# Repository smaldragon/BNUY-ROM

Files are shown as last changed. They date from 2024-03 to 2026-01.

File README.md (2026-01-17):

# BNUY-ROM

BNUY-ROM is an homebrew discrete logic mapper for the famicom/nes, which aims to have a similar level of capabilities to common ASIC mappers, while keeping a relatively low chip count. The mapper is designed to be modular, with features that can be included or ommitted depending on the needs of a game. It is similar to BNROM, hence the name.

Its capabilities are:

* Rewritable PRG-FLASH, 32K Window:
* * **39SF0x0** - Up to 512 KiB
* * **29FxxxFT** - Up to 2048KiB
* 32KiB PRG-RAM, 8K Window
* 8KiB, 32KiB or 128KiB of CHR-RAM, 4*2K Windows
* Fixed 4-Screen Nametable Arrangement
* Scanline IRQ, with MMC5-like timing

As an in-development mapper, there is currently no iNES number attributed, nor mainstream emulator support.

Render/schematic for the prototype tht version:

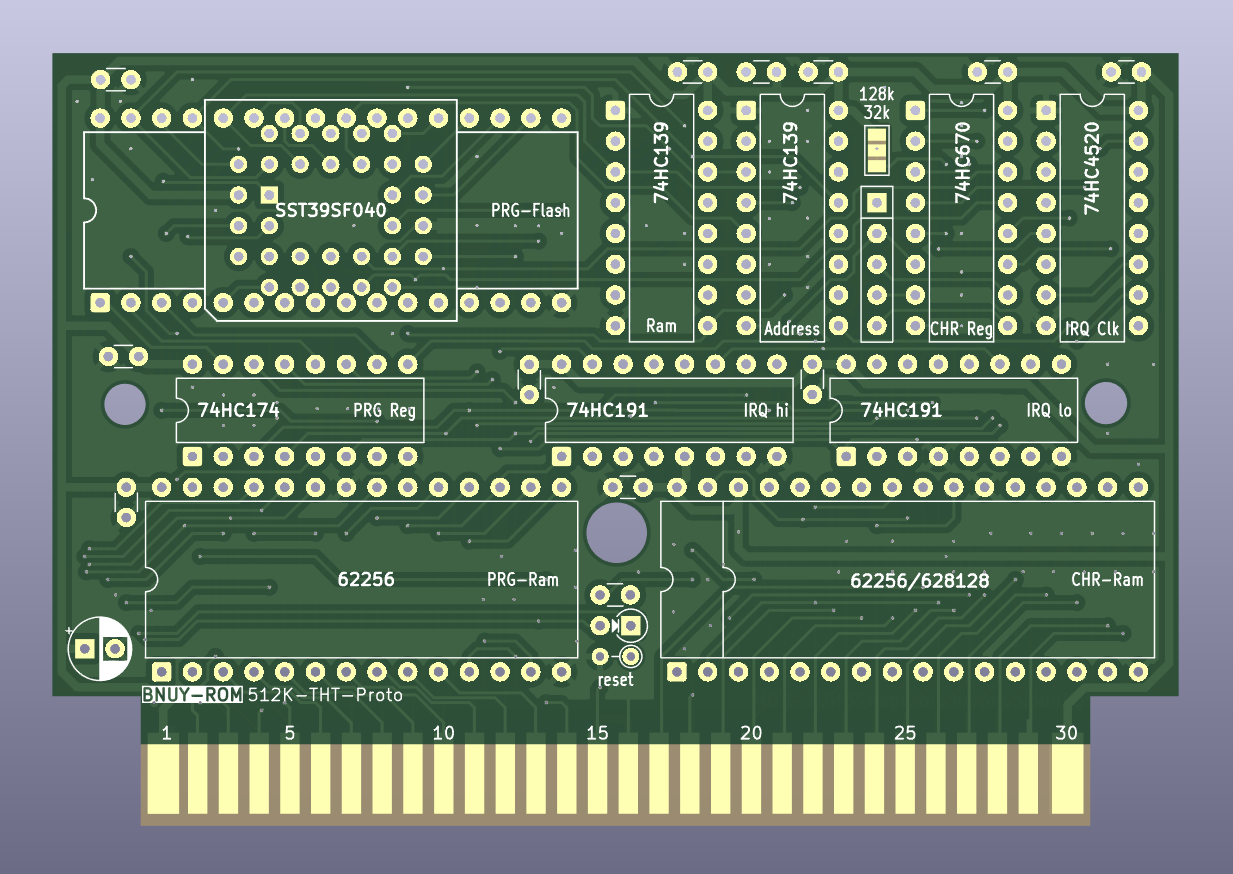
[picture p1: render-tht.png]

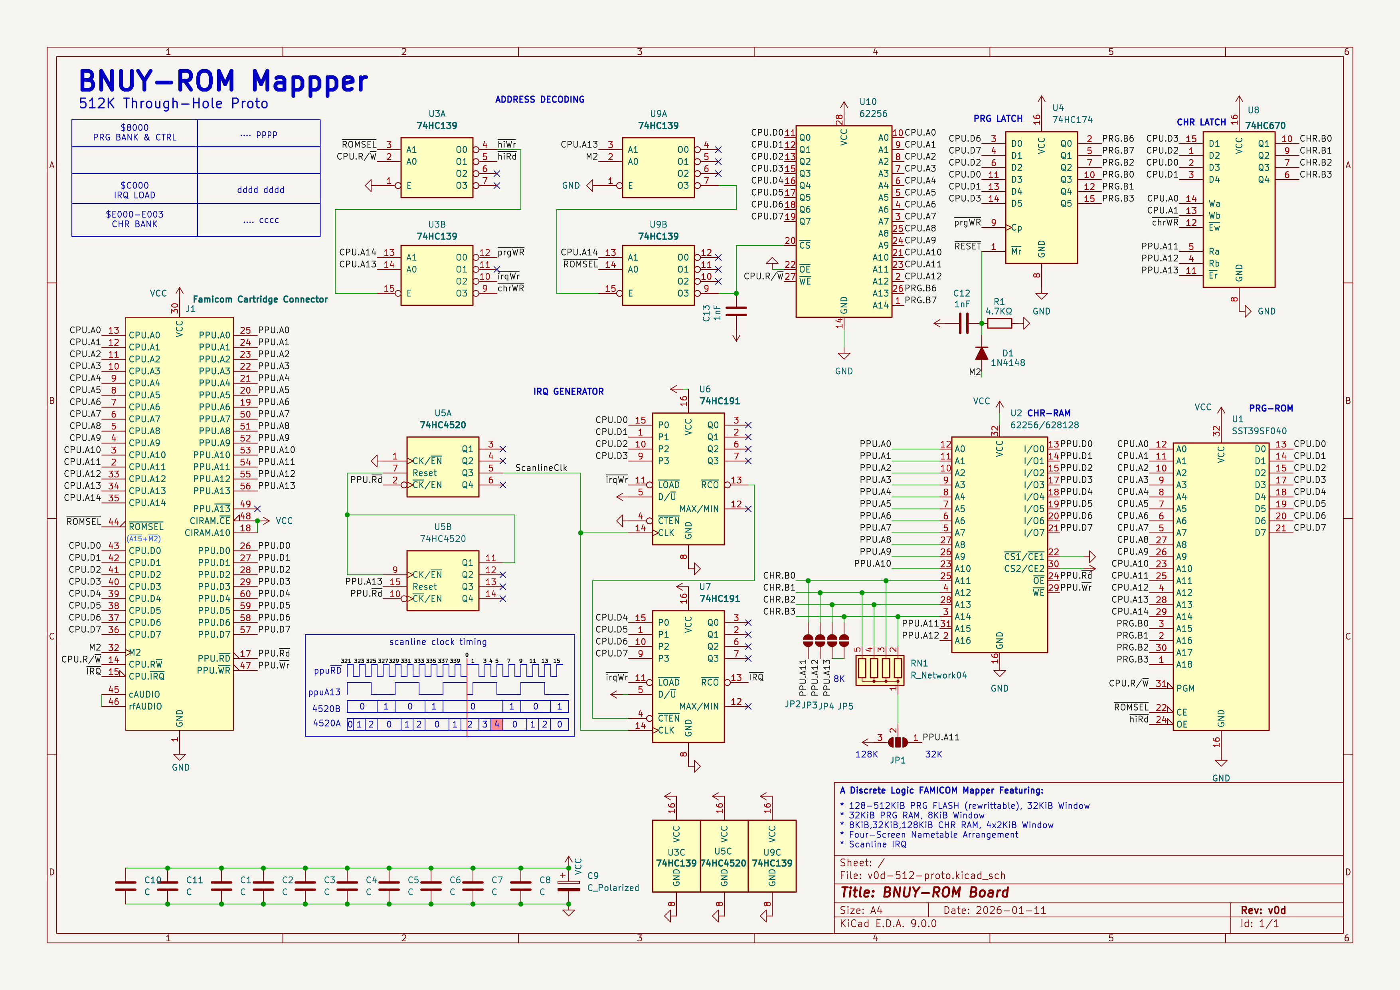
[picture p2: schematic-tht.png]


# Banks

* CPU $6000-$7FFF: 8KiB switchable PRG-RAM
* CPU $8000-$FFFF: 32 KiB switchable PRG-FLASH
* PPU $0000-$07FF: 2 KiB switchable CHR-RAM Bank
* PPU $0800-$0FFF: 2 KiB switchable CHR-RAM Bank
* PPU $1000-$17FF: 2 KiB switchable CHR-RAM Bank
* PPU $1800-$1FFF: 2 KiB switchable CHR-RAM Bank

# Registers

## PRG Banking ($8000-$9FFF, write)

This register controls the banking of PRG Flash and Ram.

```
A~100x xxxx xxxx xxxx ($8000)
D~7654 3210
  ---------
  RRPP PPPP
  ||++-++++--- PRG-Flash Bank
  ++-----------PRG-Ram Bank
```

## unused ($A000-$BFFF, write)

In previous iterations of the design, this area was used for a SAM2695 soundchip. It is now unused and avaliable for potential mapper additions.

## IRQ Counter Load ($C000-$DFFF, write)

This register will load a value into a scanline counter, which decrements once per active scanline at ppu cycle 4. The counter will continuously trigger an IRQ whenever its value is 0.

There is no mechanism to stop the counter, and it will underflow to 255 if an interrupt is ignored for 1 scanline. To stop the generator from firing, a value of 255 should be written every nmi.

```
A~110x xxxx xxxx xxxx ($C000)
D~7654 3210
  ---------
  IIII IIII
  ++++-++++- 8-bit scanline counter value
```

### Details

The 8-bit down counter is clocked by bit 2 of a prescaler counter, which increments on PPU reads with A13=1 and is cleared to zero on reads with A13=0. Normally one clock signal is generated by the prescaler per active scanline (including the pre-render scanline), but manual reads from PPU_DATA during VBlank or disabling rendering mid-frame will destabilize it. This can be overcome by reading once from A13=0 and twice from A13=1, followed by reloading the counter.

Overall the mechanism is similar to MMC5's scanline counter, but using relative values like the MMC3. Unlike the MMC3, this counter allows sprites to freely use either pattern table, including both while in 8x16 mode, and its timing simplifies scroll splits on consecutive scanlines.

It uses a x4520 to detect scanlines, and either a x40103 or two x191/x193s to hold the counter value.

## CHR Banking ($E000-$FFFF, write)

If present, these registers select one of 16 2KiB CHR-RAM banks, to use for each of the 4 PPU pattern table windows.

In **8k/linear mode**, the banking register is ommited. 16KiB of RAM are mapped to the PPU Address space, including 3840 bytes of "bonus ram" above the nametables, which the CPU may use to store values.

In **32K/shared mode**, Banks 0 and 15 are shared with the 4 nametables, and should be avoided unless special care is taken. This leaves 14 banks that can be freely distributed across the 4 windows. 

In **128K/independent mode**, the register is still 4 bits wide, but now each window has their own unique set of 16 banks (by connecting the top 2 address lines of memory to ppu A11/A12), this effectively quadruples the amount of avaliable chr-ram without adding a second register chip to the board. The first 2 windows share banks 15 with the nametables

```
A~111x xxxx xxxx xx00 ($E000)
	CHR Window 0
A~111x xxxx xxxx xx01 ($E001)
	CHR Window 1
A~111x xxxx xxxx xx10 ($E002)
	CHR Window 2
A~111x xxxx xxxx xx11 ($E003)
	CHR Window 3

D~7654 3210
  ---------
  .... BBBB
       ++++- CHR Bank Select
```

This uses a single x670 4x4 register. A second register could be added to the design for an oversize variant of 512KiB (shared) or 2048KiB (independent). A design with CHR-ROM could be used instead, at the cost of losing 4-screen nametable arrangement.

# Flash Programming

Flash programming is achieved by writing a specific sequence of command bytes to particular memory addresses, during this process flash memory cannot be read as normal, and conflicting mapper registers will have their values overwritten. As such, **flash programming code must be run from the internal 2KiB console ram, and all interrupts must be disabled**.

Flash writes operate by ANDing the written byte with the existing value in memory, with the only way to set a bit being by erasing an entire sector to `$FF`.

39SF commands listen to `A0-14`, which requires clobbering the IRQ Counter, while 29F commands listen only to `A0-A11`, allowing commands to fit in the unused `$A000-$BFFF` region.

For more information check the datasheet for your particular flash chip.

## Write Byte

### 39SF0x0

```
A~$8000 D~BANK
A~$D555 D~$AA
A~$AAAA D~$55
A~$D555 D~$A0
A~ADDR  D~DATA
```

### 29FxxxFT

```
A~$8000 D~BANK
A~$AAAA D~$AA
A~$A555 D~$55
A~$AAAA D~$A0
A~ADDR  D~DATA
```

## Erase Sector

### 39SF0x0

```
A~$8000 D~BANK
A~$D555 D~$AA
A~$AAAA D~$55
A~$D555 D~$80
A~$D555 D~$AA
A~$AAAA D~$55
A~ADDR  D~$30
```
**39SF0x0** uses uniform sectors of 4KiB,

### 29FxxxFT

```
A~$8000 D~BANK
A~$AAAA D~$AA
A~$A555 D~$55
A~$AAAA D~$80
A~$AAAA D~$AA
A~$A555 D~$55
A~ADDR  D~$30
```

**29FxxxFT** uses sectors of varying sizes depending on bank:
* Last Bank: 8KiB sectors at `$8000-$9FFF`, `$A000-$BFFF`, 16KiB sector at `$C000-$FFFF`
* Second-to-Last Bank: Single 32KiB sector
* All other banks: 64KiB sectors spanning 2 banks each.

## Write/Erase End Detect

The end of a write or erase operation can be detected by reading any memory address in flash until the same value is returned twice (toggle bit method).

## Software ID

Software ID mode can be entered to detect the manufacturer, size and type of flash chip, allowing for the same rom file to be compatible with multiple board configurations. Software ID is entered using the following command sequences:

### 39SF0x0

```
A~$8000 D~$00
A~$D555 D~$AA
A~$AAAA D~$55
A~$D555 D~$90
```

### 29FxxxFT

```
A~$8000 D~$00
A~$AAAA D~$AA
A~$A555 D~$55
A~$AAAA D~$90
```

Software ID mode is exited by writing `$F0` anywhere in flash.

### Device Code ($8001, read)

* `$B5` - 39SF010 (128KiB)
* `$B6` - 39SF020 (256KiB)
* `$B7` - 39SF040  (512KiB)
* `$51` - 29F200FT (256KiB)
* `$23` - 29F400FT (512KiB)
* `$D6` - 29F800FT (1024KiB)
* `$D2` - 29F160FT (2048KiB)

# NES 2.0 Description (tentative)

**Mapper ID**: *Unassigned*

**Flags 6 (nametable layout/flashing)**

```
D~3210
  ----
  F0BM
  | |+-- Hard-Wired Arragement
  | |      0: Vertical / 4-screen
  | |      1: Horizontal
  | +--- Uses Flash Saves
  |        0: No
  |        1: Yes
  +----- 4-Screen Arrangement
           0: Hard-Wired (using CIRAM)
           1: 4-Screen (using CHR-RAM)
```

Most games will have `%1010` here.

**Flags 8 (submapper)**

```
D~7654
  ----
  FICC
  ||++-- CHR Banking Mode
  ||        0: 8K/Linear (no banking)
  ||        1: 32K/Shared (all banks avaliable in every window)
  ||        2: 128K/Independent (all windows have unique sets of banks)
  |+---- Interrupt Generator
  |         0: No IRQ
  |         1: Has IRQ
  +----- Flash Memory Type
            0: 39SF0x0 (sizes of 128K, 256K, 512K)
            1: 29FxxxFT (sizes of 256K, 512K, 1024K, 2048K)
```

**PRG-ROM, PRG-RAM and CHR-RAM size**

Size should match the memory accessible on the board.

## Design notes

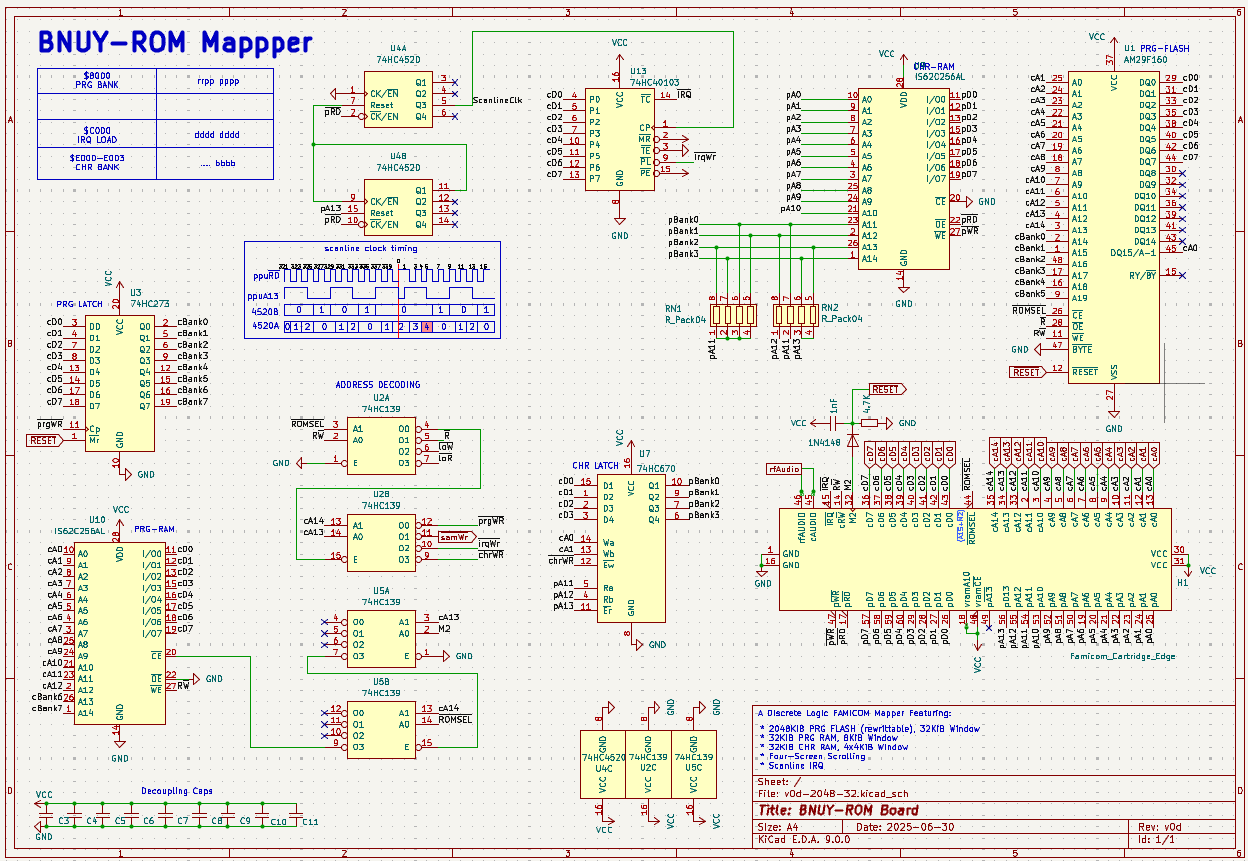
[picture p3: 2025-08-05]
schematic-smd.png

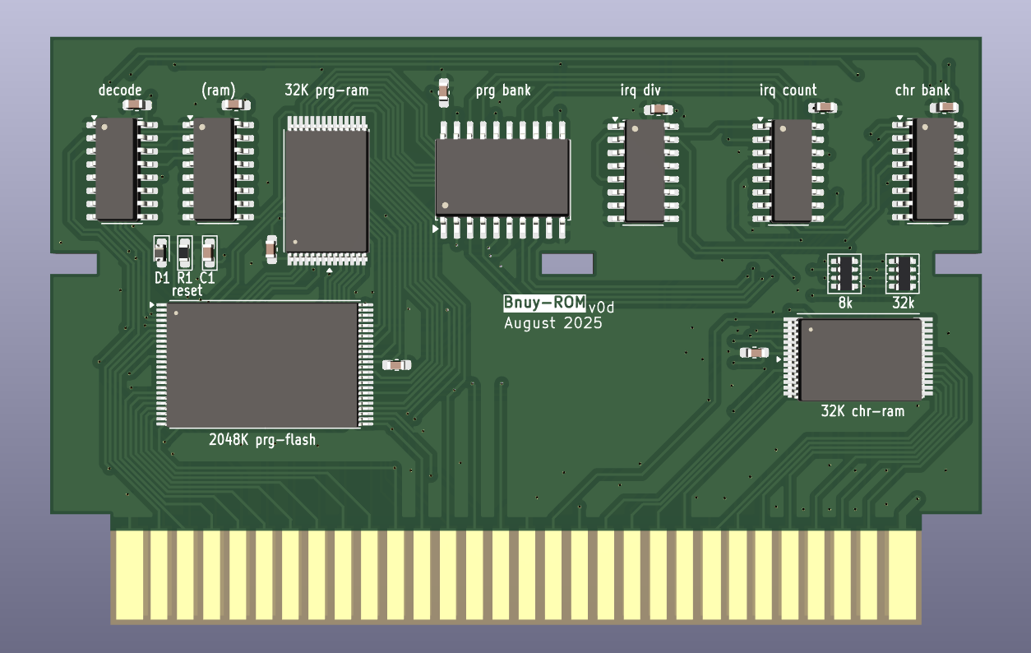
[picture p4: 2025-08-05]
render-smd.png

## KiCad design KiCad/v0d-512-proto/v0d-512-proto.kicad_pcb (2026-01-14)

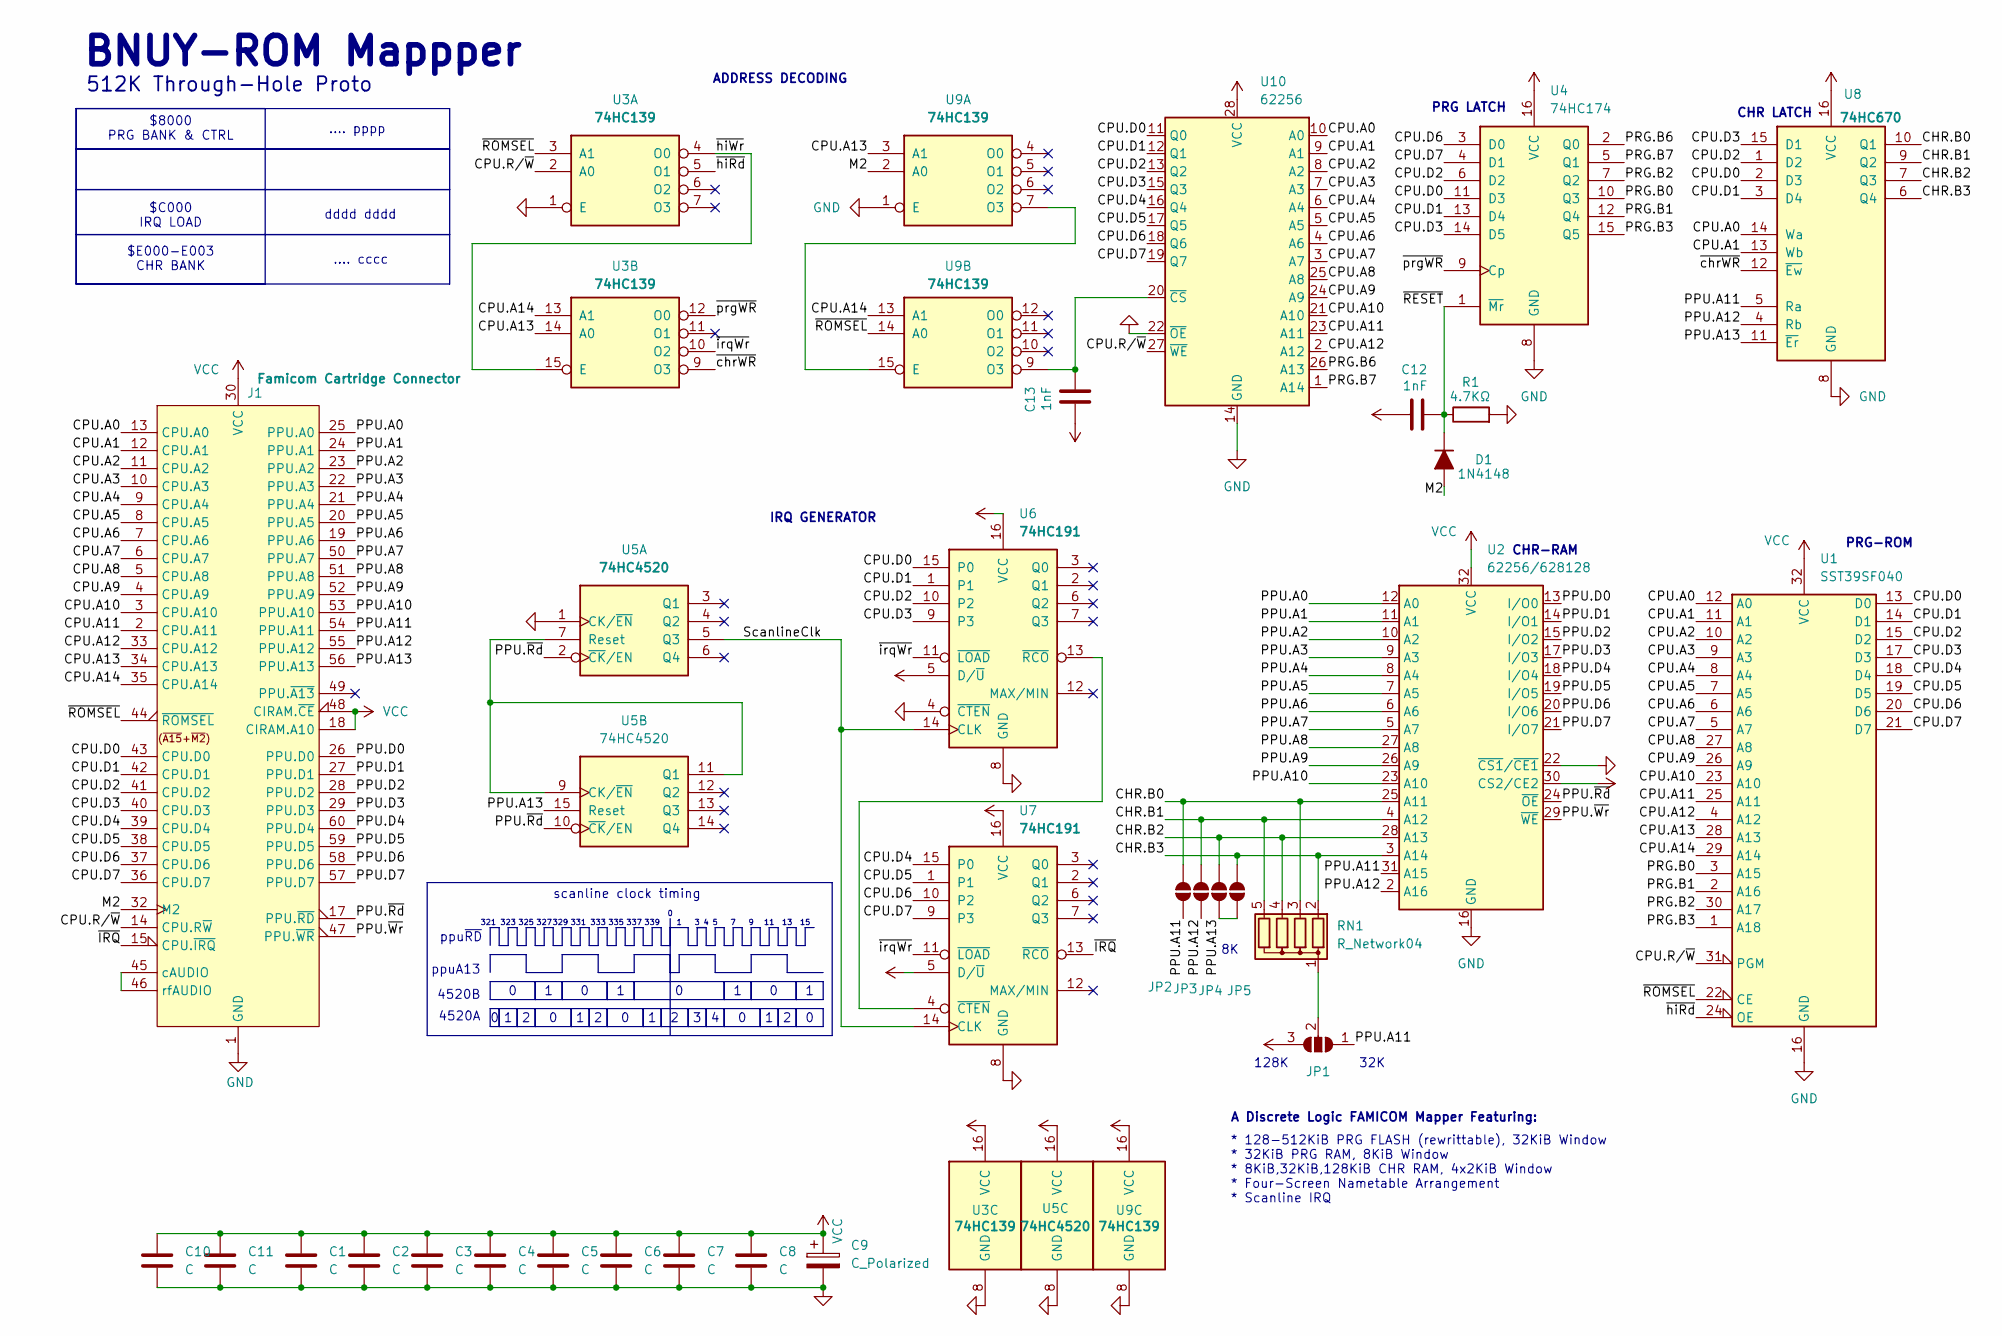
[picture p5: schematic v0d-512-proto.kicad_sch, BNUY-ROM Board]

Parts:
C1, C2, C3, C4, C5, C6, C7, C8, C10, C11: C; C_Disc_D3.0mm_W1.6mm_P2.50mm
C9: C_Polarized; CP_Radial_D5.0mm_P2.50mm
C12, C13: 1nF; C_Disc_D3.0mm_W1.6mm_P2.50mm
D1: 1N4148; D_DO-35_SOD27_P2.54mm_Vertical_AnodeUp
J1: Famicom Cartridge Connector; Famicom Cartridge Edge Connector (long legs)
JP1: SolderJumper_3_Open; SolderJumper-3_P1.3mm_Open_Pad1.0x1.5mm_NumberLabels
JP2, JP3, JP4, JP5: SolderJumper_2_Open; SolderJumper-2_P1.3mm_Open_Pad1.0x1.5mm
R1: 4.7KΩ; R_Axial_DIN0204_L3.6mm_D1.6mm_P2.54mm_Vertical
RN1: R_Network04; R_Array_SIP5
U1: SST39SF040; PLCC-DIP-32_THT-Socket
U2: 62256/628128; DIP-32_W15.24mm
U3, U9: 74HC139; DIP-16_W7.62mm
U4: 74HC174; DIP-16_W7.62mm
U5: 74HC4520; DIP-16_W7.62mm
U6, U7: 74HC191; DIP-16_W7.62mm
U8: 74HC670; DIP-16_W7.62mm
U10: 62256; DIP-28_W15.24mm

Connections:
/CHR.B0: JP2.1 (A), RN1.3 (R2), U2.25 (A11), U8.10 (Q1)
/CHR.B1: JP3.1 (A), RN1.5 (R4), U2.4 (A12), U8.9 (Q2)
/CHR.B2: JP4.1 (A), RN1.4 (R3), U2.28 (A13), U8.7 (Q3)
/CHR.B3: JP5.1 (A), RN1.2 (R1), U2.3 (A14), U8.6 (Q4)
/CPU.A0: J1.13 (CPU.A0), U1.12 (A0), U8.14 (Wa), U10.10 (A0)
/CPU.A1: J1.12 (CPU.A1), U1.11 (A1), U8.13 (Wb), U10.9 (A1)
/CPU.A2: J1.11 (CPU.A2), U1.10 (A2), U10.8 (A2)
/CPU.A3: J1.10 (CPU.A3), U1.9 (A3), U10.7 (A3)
/CPU.A4: J1.9 (CPU.A4), U1.8 (A4), U10.6 (A4)
/CPU.A5: J1.8 (CPU.A5), U1.7 (A5), U10.5 (A5)
/CPU.A6: J1.7 (CPU.A6), U1.6 (A6), U10.4 (A6)
/CPU.A7: J1.6 (CPU.A7), U1.5 (A7), U10.3 (A7)
/CPU.A8: J1.5 (CPU.A8), U1.27 (A8), U10.25 (A8)
/CPU.A9: J1.4 (CPU.A9), U1.26 (A9), U10.24 (A9)
/CPU.A10: J1.3 (CPU.A10), U1.23 (A10), U10.21 (A10)
/CPU.A11: J1.2 (CPU.A11), U1.25 (A11), U10.23 (A11)
/CPU.A12: J1.33 (CPU.A12), U1.4 (A12), U10.2 (A12)
/CPU.A13: J1.34 (CPU.A13), U1.28 (A13), U3.14 (A0), U9.3 (A1)
/CPU.A14: J1.35 (CPU.A14), U1.29 (A14), U3.13 (A1), U9.13 (A1)
/CPU.D0: J1.43 (CPU.D0), U1.13 (D0), U4.11 (D3), U6.15 (P0), U8.2 (D3), U10.11 (Q0)
/CPU.D1: J1.42 (CPU.D1), U1.14 (D1), U4.13 (D4), U6.1, U8.3 (D4), U10.12 (Q1)
/CPU.D2: J1.41 (CPU.D2), U1.15 (D2), U4.6 (D2), U6.10 (P2), U8.1 (D2), U10.13 (Q2)
/CPU.D3: J1.40 (CPU.D3), U1.17 (D3), U4.14 (D5), U6.9 (P3), U8.15 (D1), U10.15 (Q3)
/CPU.D4: J1.39 (CPU.D4), U1.18 (D4), U7.15 (P0), U10.16 (Q4)
/CPU.D5: J1.38 (CPU.D5), U1.19 (D5), U7.1, U10.17 (Q5)
/CPU.D6: J1.37 (CPU.D6), U1.20 (D6), U4.3 (D0), U7.10 (P2), U10.18 (Q6)
/CPU.D7: J1.36 (CPU.D7), U1.21 (D7), U4.4 (D1), U7.9 (P3), U10.19 (Q7)
/CPU.R/~W: J1.14 (CPU.R~W), U1.31 (PGM), U3.2 (A0), U10.27 (~WE)
/M2: D1.2 (A), J1.32 (M2), U9.2 (A0)
/PPU.A0: J1.25 (PPU.A0), U2.12 (A0)
/PPU.A1: J1.24 (PPU.A1), U2.11 (A1)
/PPU.A2: J1.23 (PPU.A2), U2.10 (A2)
/PPU.A3: J1.22 (PPU.A3), U2.9 (A3)
/PPU.A4: J1.21 (PPU.A4), U2.8 (A4)
/PPU.A5: J1.20 (PPU.A5), U2.7 (A5)
/PPU.A6: J1.19 (PPU.A6), U2.6 (A6)
/PPU.A7: J1.50 (PPU.A7), U2.5 (A7)
/PPU.A8: J1.51 (PPU.A8), U2.27 (A8)
/PPU.A9: J1.52 (PPU.A9), U2.26 (A9)
/PPU.A10: J1.53 (PPU.A10), U2.23 (A10)
/PPU.A11: J1.54 (PPU.A11), JP1.1 (A), JP2.2 (B), U2.31 (A15), U8.5 (Ra)
/PPU.A12: J1.55 (PPU.A12), JP3.2 (B), U2.2 (A16), U8.4 (Rb)
/PPU.A13: J1.56 (PPU.A13), JP4.2 (B), JP5.2 (B), U5.15 (Reset), U8.11 (~Er)
/PPU.D0: J1.26 (PPU.D0), U2.13 (I/O0)
/PPU.D1: J1.27 (PPU.D1), U2.14 (I/O1)
/PPU.D2: J1.28 (PPU.D2), U2.15 (I/O2)
/PPU.D3: J1.29 (PPU.D3), U2.17 (I/O3)
/PPU.D4: J1.60 (PPU.D4), U2.18 (I/O4)
/PPU.D5: J1.59 (PPU.D5), U2.19 (I/O5)
/PPU.D6: J1.58 (PPU.D6), U2.20 (I/O6)
/PPU.D7: J1.57 (PPU.D7), U2.21 (I/O7)
/PPU.~Rd: J1.17 (PPU.~RD), U2.24 (~OE), U5.2 (~CK/EN), U5.10 (~CK/EN)
/PPU.~Wr: J1.47 (PPU.~WR), U2.29 (~WE)
/PRG.B0: U1.3 (A15), U4.10 (Q3)
/PRG.B1: U1.2 (A16), U4.12 (Q4)
/PRG.B2: U1.30 (A17), U4.7 (Q2)
/PRG.B3: U1.1 (A18), U4.15 (Q5)
/PRG.B6: U4.2 (Q0), U10.26 (A13)
/PRG.B7: U4.5 (Q1), U10.1 (A14)
/ScanlineClk: U5.5 (Q3), U6.14 (CLK), U7.14 (CLK)
/~IRQ: J1.15 (CPU.~IRQ), U7.13 (~RCO)
/~RESET: C12.2, D1.1 (K), R1.1, U4.1 (~Mr)
/~ROMSEL: J1.44 (~ROMSEL), U1.22 (CE), U3.3 (A1), U9.14 (A0)
/~chrWR: U3.9 (O3), U8.12 (~Ew)
/~hiRd: U1.24 (OE), U3.5 (O1)
/~hiWr: U3.4 (O0), U3.15 (E)
/~irqWr: U3.10 (O2), U6.11 (~LOAD), U7.11 (~LOAD)
/~prgWR: U3.12 (O0), U4.9 (Cp)
GND: C1.2, C2.2, C3.2, C4.2, C5.2, C6.2, C7.2, C8.2, C9.2, C10.2, C11.2, J1.1 (GND), J1.16 (GND), R1.2, U1.16 (GND), U2.16 (GND), U2.22 (~CS1/~CE1), U3.1 (E), U3.8 (GND), U4.8 (GND), U5.1 (CK/~EN), U5.8 (GND), U6.4 (~CTEN), U6.8 (GND), U7.8 (GND), U8.8 (GND), U9.1 (E), U9.8 (GND), U10.14 (GND), U10.22 (~OE)
unnamed: J1.45 (cAUDIO), J1.46 (rfAUDIO)
unnamed: JP1.2 (C), RN1.1 (common)
unnamed: U5.7 (Reset), U5.9 (CK/~EN), U5.11 (Q1)
unnamed: U6.13 (~RCO), U7.4 (~CTEN)
unnamed: U9.7 (O3), U9.15 (E)
unnamed: C13.2, U9.9 (O3), U10.20 (~CS)
VCC: C1.1, C2.1, C3.1, C4.1, C5.1, C6.1, C7.1, C8.1, C9.1, C10.1, C11.1, C12.1, C13.1, J1.18 (CIRAM.A10), J1.30 (VCC), J1.31 (VCC), J1.48 (CIRAM.~CE), JP1.3 (B), U1.32 (VCC), U2.30 (CS2/CE2), U2.32 (VCC), U3.16 (VCC), U4.16 (VCC), U5.16 (VCC), U6.5 (D/~U), U6.16 (VCC), U7.5 (D/~U), U7.16 (VCC), U8.16 (VCC), U9.16 (VCC), U10.28 (VCC)

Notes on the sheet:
BNUY-ROM Mappper
335
321
.... pppp
* 128-512KiB PRG FLASH (rewrittable), 32KiB Window * 32KiB PRG RAM, 8KiB Window * 8KiB,32KiB,128KiB CHR RAM, 4x2KiB Window * Four-Screen Nametable Arrangement * Scanline IRQ
325
512K Through-Hole Proto
4520B
ADDRESS DECODING
327
339
ppuA13
CHR-RAM
dddd dddd
333
337
.... cccc
4520A
329
CHR LATCH
323
128K
A Discrete Logic FAMICOM Mapper Featuring:
PRG-ROM
scanline clock timing
IRQ GENERATOR
PRG LATCH
32K
331
ppu~{RD}
$8000 PRG BANK & CTRL $C000 IRQ LOAD $E000-E003 CHR BANK

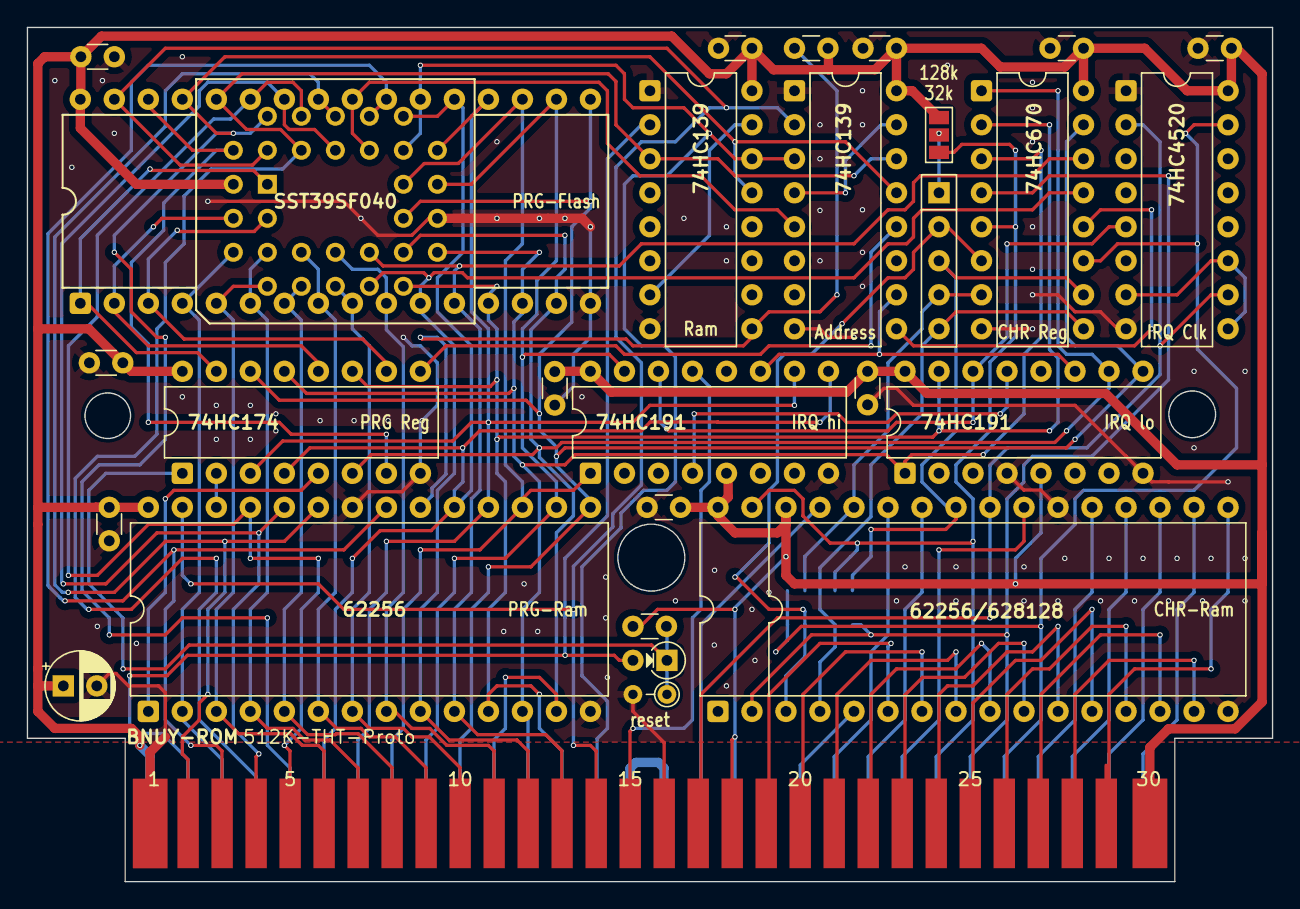
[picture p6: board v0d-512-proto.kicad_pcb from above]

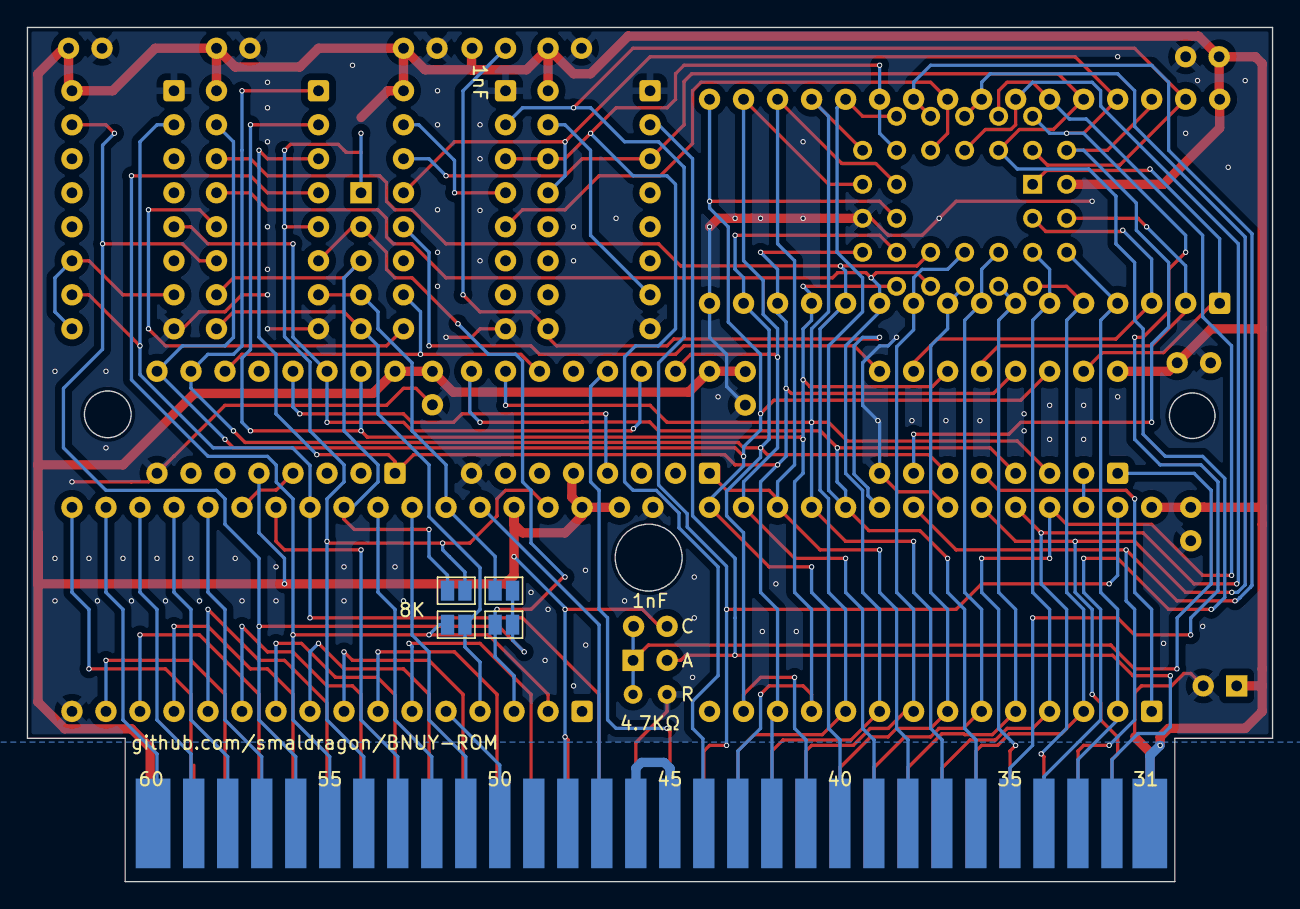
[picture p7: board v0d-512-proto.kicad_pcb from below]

Board: 2 copper layers, 93.0 x 63.8 mm, 32 parts (4 on the bottom side), 76 nets.

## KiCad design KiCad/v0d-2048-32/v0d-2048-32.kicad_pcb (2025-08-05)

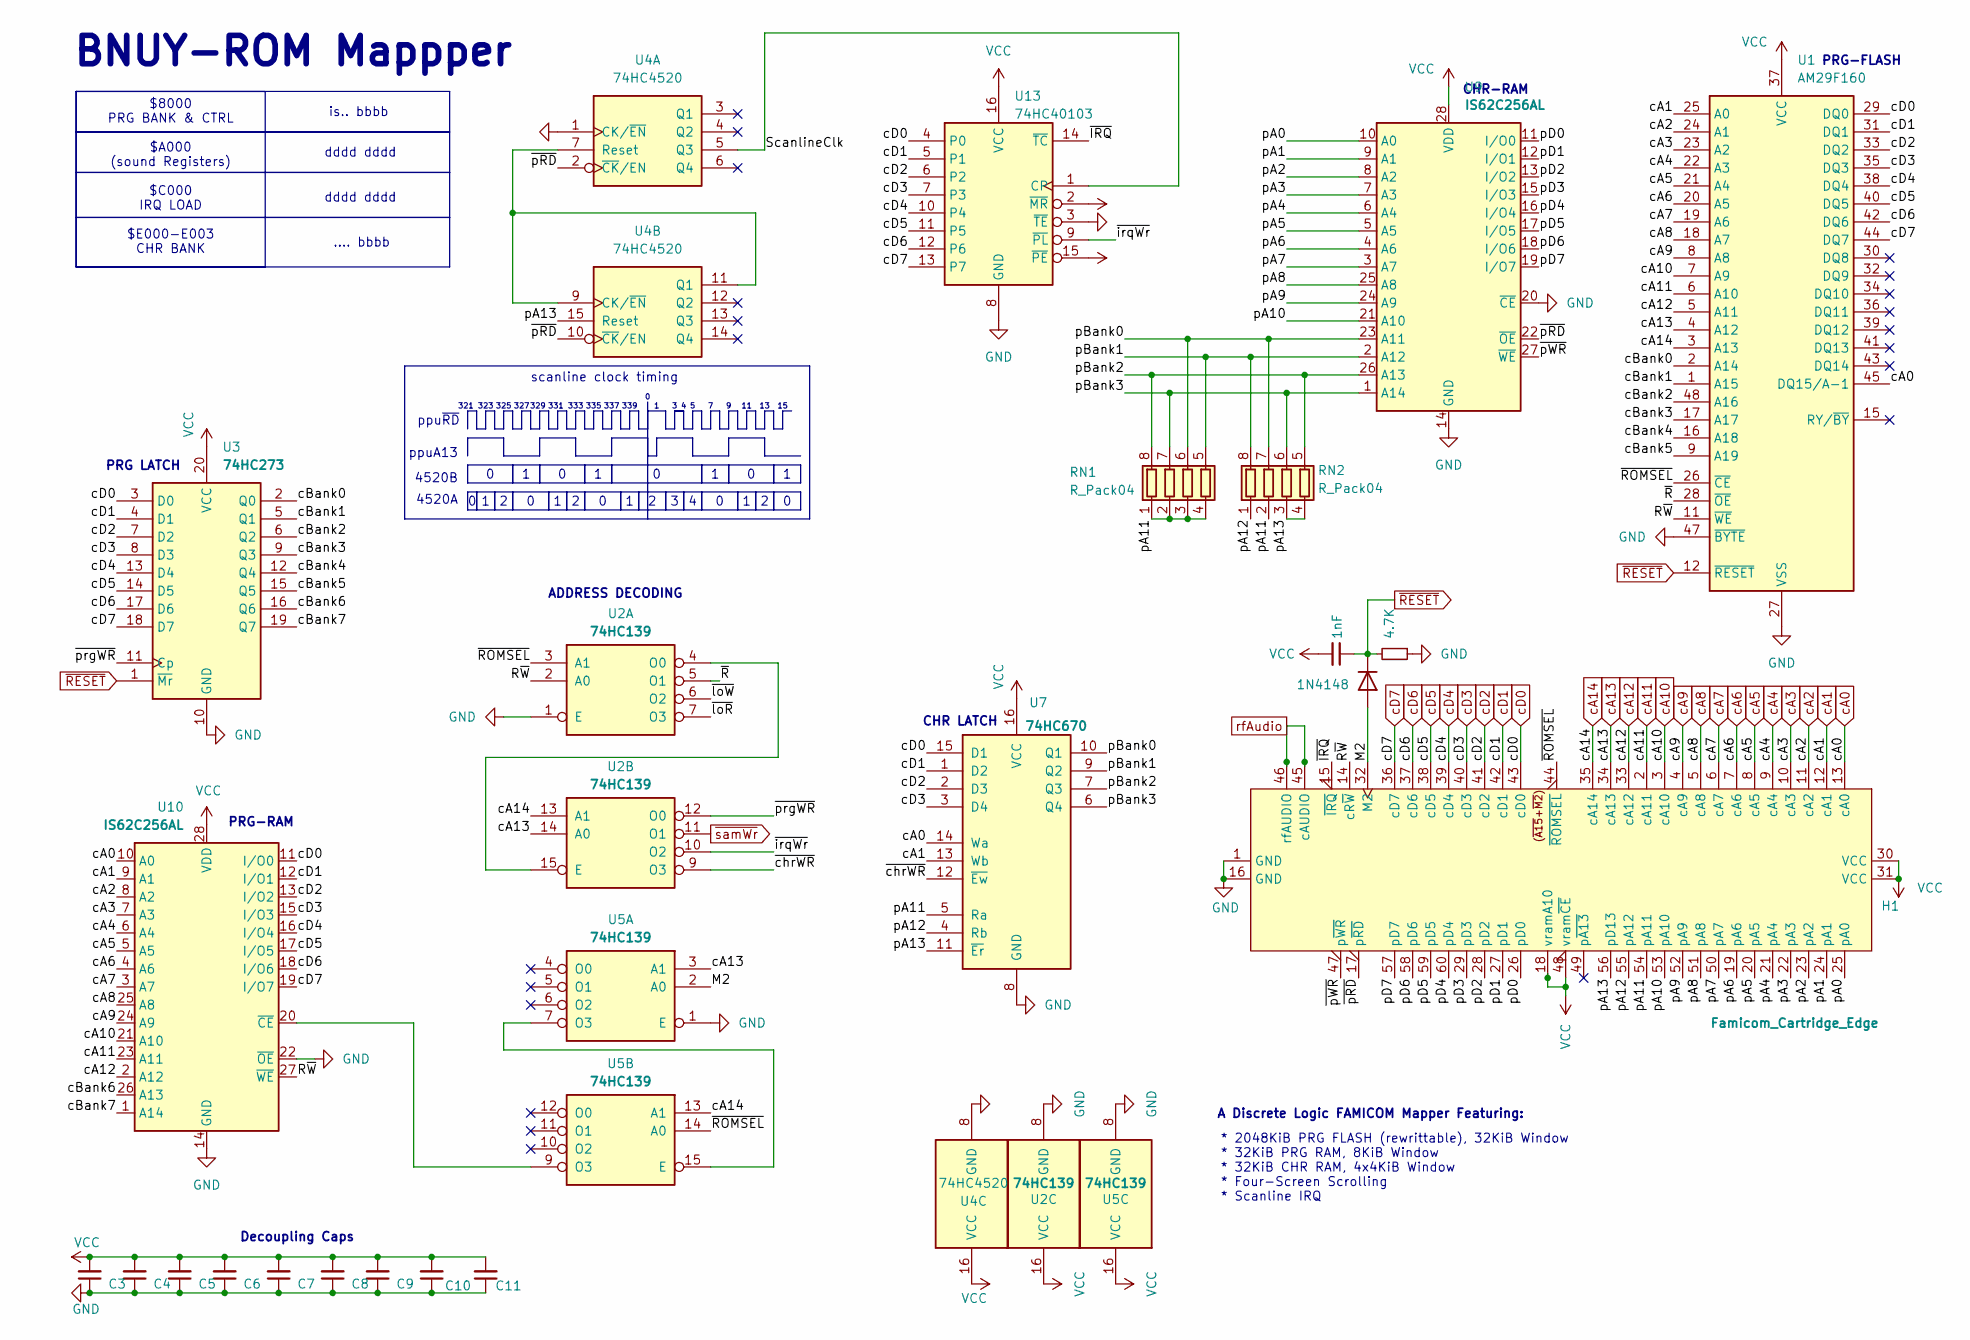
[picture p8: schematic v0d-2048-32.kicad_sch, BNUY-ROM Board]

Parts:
C1: 1nF; C_0603_1608Metric_Pad1.08x0.95mm_HandSolder
C3, C4, C5, C6, C7, C8, C9, C10, C11: C_Small; C_0603_1608Metric_Pad1.08x0.95mm_HandSolder
D1: 1N4148; D_0603_1608Metric_Pad1.05x0.95mm_HandSolder
H1: Famicom_Cartridge_Edge; Famicom Cartridge Edge Connector (long legs)
R1: 4.7K; R_0603_1608Metric_Pad1.05x0.95mm_HandSolder
RN1, RN2: R_Pack04; R_Array_Convex_4x0603
U1: AM29F160; TSOP-I-48_18.4x12mm_P0.5mm
U2, U5: 74HC139; SOIC-16_3.9x9.9mm_P1.27mm
U3: 74HC273; SOIC-20W_7.5x12.8mm_P1.27mm
U4: 74HC4520; SOIC-16_3.9x9.9mm_P1.27mm
U7: 74HC670; SOIC-16_3.9x9.9mm_P1.27mm
U9, U10: IS62C256AL; TSOP-I-28_11.8x8mm_P0.55mm_MiddlePin
U13: 74HC40103; SOIC-16_3.9x9.9mm_P1.27mm

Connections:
/M2: D1.2 (A), H1.32 (M2), U5.2 (A0)
/R~W: H1.14 (cR~W), U1.11 (~WE), U2.2 (A0), U10.27 (~WE)
/ScanlineClk: U4.5 (Q3), U13.1 (CP)
/cBank0: U1.2 (A14), U3.2 (Q0)
/cBank1: U1.1 (A15), U3.5 (Q1)
/cBank2: U1.48 (A16), U3.6 (Q2)
/cBank3: U1.17 (A17), U3.9 (Q3)
/cBank4: U1.16 (A18), U3.12 (Q4)
/cBank5: U1.9 (A19), U3.15 (Q5)
/cBank6: U3.16 (Q6), U10.26 (A13)
/cBank7: U3.19 (Q7), U10.1 (A14)
/pA0: H1.25 (pA0), U9.10 (A0)
/pA1: H1.24 (pA1), U9.9 (A1)
/pA2: H1.23 (pA2), U9.8 (A2)
/pA3: H1.22 (pA3), U9.7 (A3)
/pA4: H1.21 (pA4), U9.6 (A4)
/pA5: H1.20 (pA5), U9.5 (A5)
/pA6: H1.19 (pA6), U9.4 (A6)
/pA7: H1.50 (pA7), U9.3 (A7)
/pA8: H1.51 (pA8), U9.25 (A8)
/pA9: H1.52 (pA9), U9.24 (A9)
/pA10: H1.53 (pA10), U9.21 (A10)
/pA11: H1.54 (pA11), RN1.1 (R1.1), RN1.2 (R2.1), RN1.3 (R3.1), RN1.4 (R4.1), RN2.2 (R2.1), U7.5 (Ra)
/pA12: H1.55 (pA12), RN2.1 (R1.1), U7.4 (Rb)
/pA13: H1.56 (pD13), RN2.3 (R3.1), RN2.4 (R4.1), U4.15 (Reset), U7.11 (~Er)
/pBank0: RN1.6 (R3.2), RN2.7 (R2.2), U7.10 (Q1), U9.23 (A11)
/pBank1: RN1.5 (R4.2), RN2.8 (R1.2), U7.9 (Q2), U9.2 (A12)
/pBank2: RN1.8 (R1.2), RN2.5 (R4.2), U7.7 (Q3), U9.26 (A13)
/pBank3: RN1.7 (R2.2), RN2.6 (R3.2), U7.6 (Q4), U9.1 (A14)
/pD0: H1.26 (pD0), U9.11 (I/O0)
/pD1: H1.27 (pD1), U9.12 (I/O1)
/pD2: H1.28 (pD2), U9.13 (I/O2)
/pD3: H1.29 (pD3), U9.15 (I/O3)
/pD4: H1.60 (pD4), U9.16 (I/O4)
/pD5: H1.59 (pD5), U9.17 (I/O5)
/pD6: H1.58 (pD6), U9.18 (I/O6)
/pD7: H1.57 (pD7), U9.19 (I/O7)
/~IRQ: H1.15 (~IRQ), U13.14 (~TC)
/~ROMSEL: H1.44 (~ROMSEL), U1.26 (~CE), U2.3 (A1), U5.14 (A0)
/~R: U1.28 (~OE), U2.5 (O1)
/~chrWR: U2.9 (O3), U7.12 (~Ew)
/~irqWr: U2.10 (O2), U13.9 (~PL)
/~loR: U2.7 (O3)
/~loW: U2.6 (O2)
/~pRD: H1.17 (p~RD), U4.2 (~CK/EN), U4.10 (~CK/EN), U9.22 (~OE)
/~pWR: H1.47 (p~WR), U9.27 (~WE)
/~prgWR: U2.12 (O0), U3.11 (Cp)
GND: C3.1, C4.1, C5.1, C6.1, C7.1, C8.1, C9.1, C10.1, C11.1, H1.1 (GND), H1.16 (GND), R1.1, U1.27 (VSS), U1.47 (~BYTE), U2.1 (E), U2.8 (GND), U3.10 (GND), U4.1 (CK/~EN), U4.8 (GND), U5.1 (E), U5.8 (GND), U7.8 (GND), U9.14 (GND), U9.20 (~CE), U10.14 (GND), U10.22 (~OE), U13.3 (~TE), U13.8 (GND)
unnamed: U2.4 (O0), U2.15 (E)
unnamed: U4.7 (Reset), U4.9 (CK/~EN), U4.11 (Q1)
unnamed: U5.7 (O3), U5.15 (E)
unnamed: U5.9 (O3), U10.20 (~CE)
VCC: C1.2, C3.2, C4.2, C5.2, C6.2, C7.2, C8.2, C9.2, C10.2, C11.2, H1.18 (vramA10), H1.30 (VCC), H1.31 (VCC), H1.48 (vram~CE), U1.37 (VCC), U2.16 (VCC), U3.20 (VCC), U4.16 (VCC), U5.16 (VCC), U7.16 (VCC), U9.28 (VDD), U10.28 (VDD), U13.2 (~MR), U13.15 (~PE), U13.16 (VCC)
cA0: H1.13 (cA0), U1.45 (DQ15/A-1), U7.14 (Wa), U10.10 (A0)
cA1: H1.12 (cA1), U1.25 (A0), U7.13 (Wb), U10.9 (A1)
cA2: H1.11 (cA2), U1.24 (A1), U10.8 (A2)
cA3: H1.10 (cA3), U1.23 (A2), U10.7 (A3)
cA4: H1.9 (cA4), U1.22 (A3), U10.6 (A4)
cA5: H1.8 (cA5), U1.21 (A4), U10.5 (A5)
cA6: H1.7 (cA6), U1.20 (A5), U10.4 (A6)
cA7: H1.6 (cA7), U1.19 (A6), U10.3 (A7)
cA8: H1.5 (cA8), U1.18 (A7), U10.25 (A8)
cA9: H1.4 (cA9), U1.8 (A8), U10.24 (A9)
cA10: H1.3 (cA10), U1.7 (A9), U10.21 (A10)
cA11: H1.2 (cA11), U1.6 (A10), U10.23 (A11)
cA12: H1.33 (cA12), U1.5 (A11), U10.2 (A12)
cA13: H1.34 (cA13), U1.4 (A12), U2.14 (A0), U5.3 (A1)
cA14: H1.35 (cA14), U1.3 (A13), U2.13 (A1), U5.13 (A1)
cD0: H1.43 (cD0), U1.29 (DQ0), U3.3 (D0), U7.15 (D1), U10.11 (I/O0), U13.4 (P0)
cD1: H1.42 (cD1), U1.31 (DQ1), U3.4 (D1), U7.1 (D2), U10.12 (I/O1), U13.5 (P1)
cD2: H1.41 (cD2), U1.33 (DQ2), U3.7 (D2), U7.2 (D3), U10.13 (I/O2), U13.6 (P2)
cD3: H1.40 (cD3), U1.35 (DQ3), U3.8 (D3), U7.3 (D4), U10.15 (I/O3), U13.7 (P3)
cD4: H1.39 (cD4), U1.38 (DQ4), U3.13 (D4), U10.16 (I/O4), U13.10 (P4)
cD5: H1.38 (cD5), U1.40 (DQ5), U3.14 (D5), U10.17 (I/O5), U13.11 (P5)
cD6: H1.37 (cD6), U1.42 (DQ6), U3.17 (D6), U10.18 (I/O6), U13.12 (P6)
cD7: H1.36 (cD7), U1.44 (DQ7), U3.18 (D7), U10.19 (I/O7), U13.13 (P7)
rfAudio: H1.45 (cAUDIO), H1.46 (rfAUDIO)
~RESET: C1.1, D1.1 (K), R1.2, U1.12 (~RESET), U3.1 (~Mr)
~samWr: U2.11 (O1)

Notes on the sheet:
BNUY-ROM Mappper
335
321
is.. bbbb
* 2048KiB PRG FLASH (rewrittable), 32KiB Window * 32KiB PRG RAM, 8KiB Window * 32KiB CHR RAM, 4x4KiB Window * Four-Screen Scrolling * Scanline IRQ
325
4520B
ADDRESS DECODING
327
339
ppuA13
CHR-RAM
dddd dddd
333
337
.... bbbb
4520A
PRG-RAM
329
CHR LATCH
323
A Discrete Logic FAMICOM Mapper Featuring:
Decoupling Caps
PRG-FLASH
scanline clock timing
PRG LATCH
331
ppu~{RD}
$8000 PRG BANK & CTRL $A000 (sound Registers) $C000 IRQ LOAD $E000-E003 CHR BANK

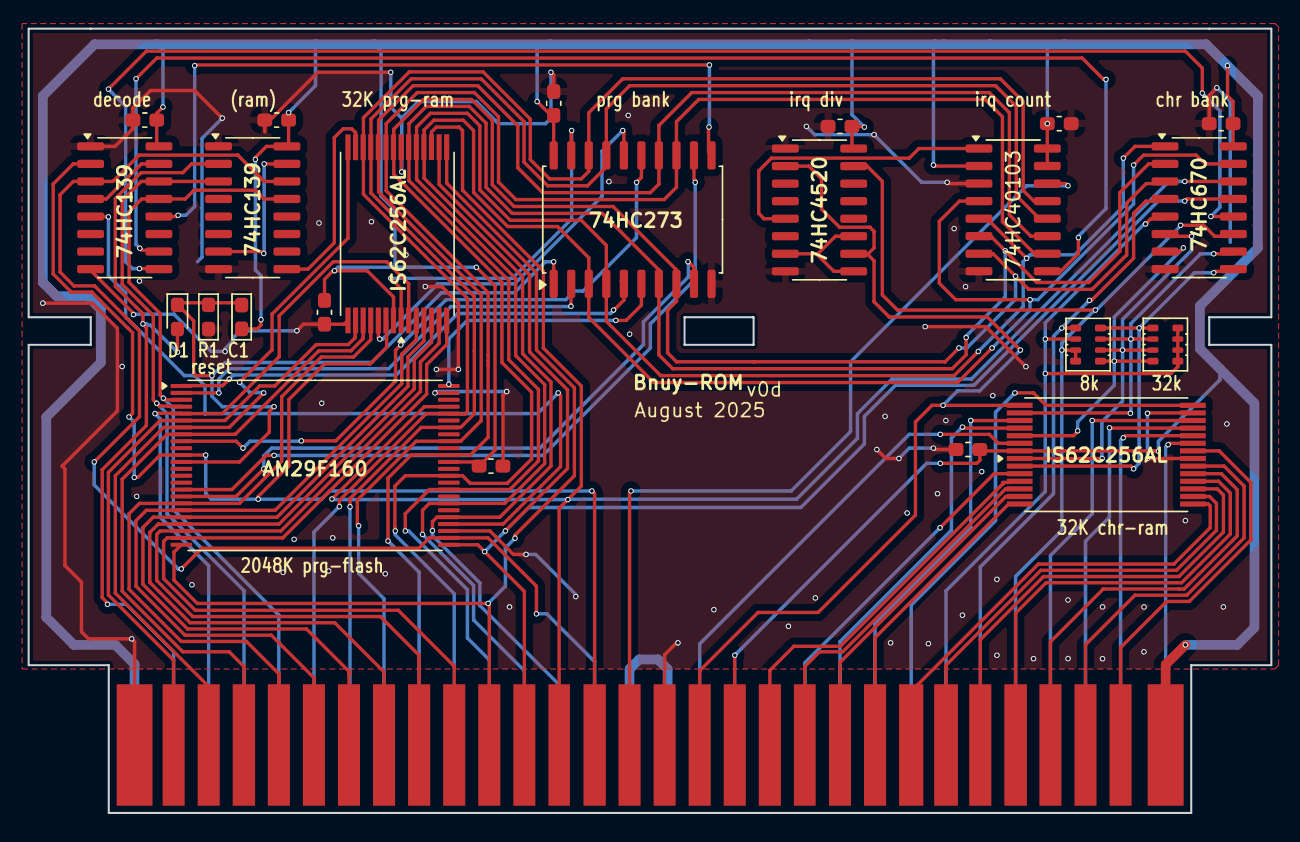
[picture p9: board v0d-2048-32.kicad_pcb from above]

Board: 2 copper layers, 90.0 x 56.8 mm, 24 parts (0 on the bottom side), 76 nets.

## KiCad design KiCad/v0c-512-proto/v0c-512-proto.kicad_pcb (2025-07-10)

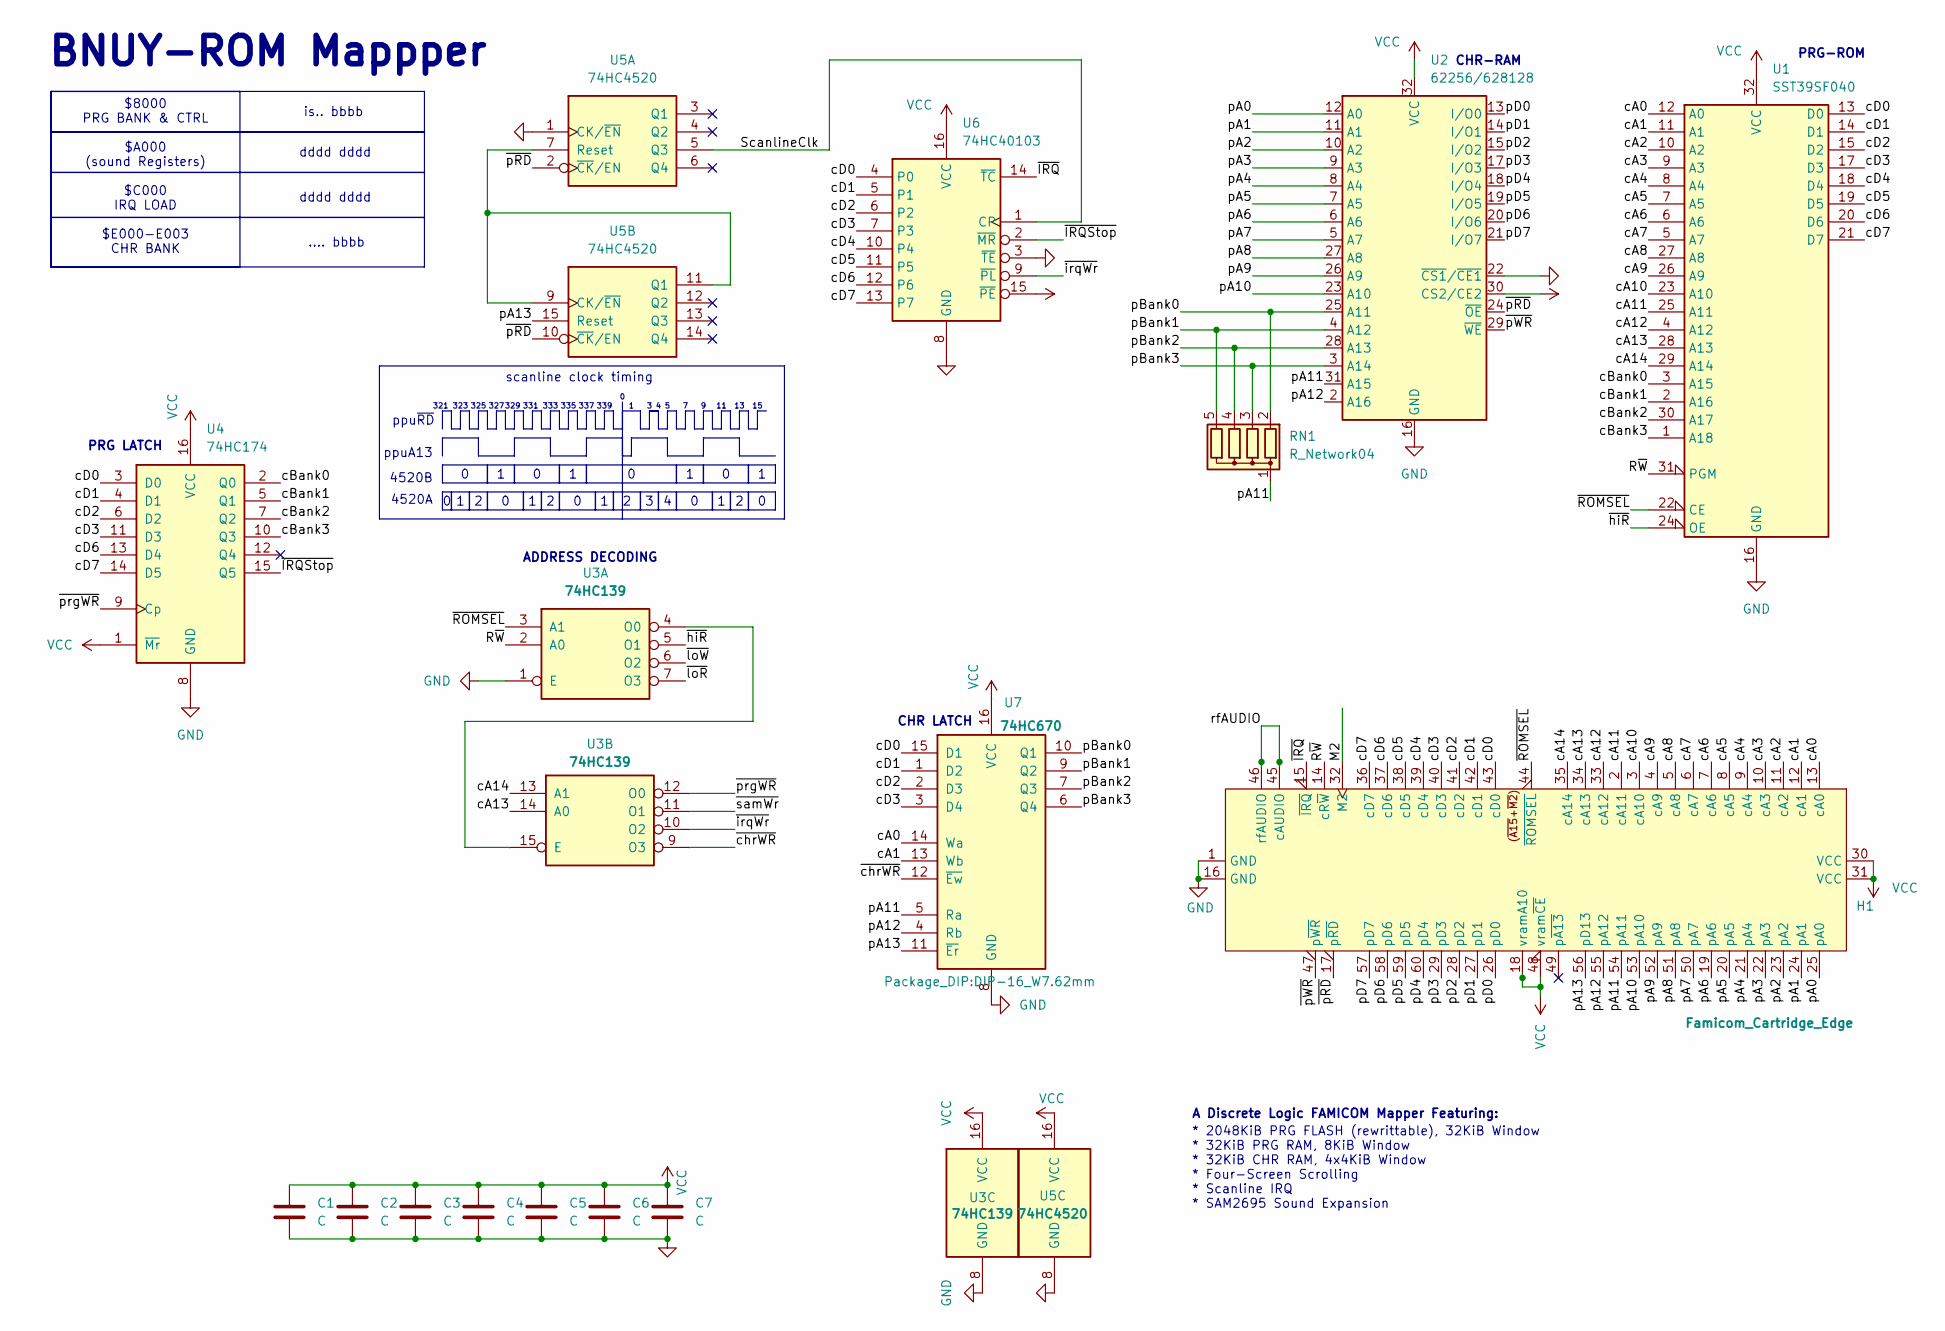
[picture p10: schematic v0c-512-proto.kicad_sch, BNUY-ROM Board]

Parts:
C1, C2, C3, C4, C5, C6, C7: C; C_Disc_D3.0mm_W1.6mm_P2.50mm
H1: Famicom_Cartridge_Edge; Famicom Cartridge Edge Connector (long legs)
RN1: R_Network04; R_Array_SIP5
U1: SST39SF040; PLCC-DIP-32_THT-Socket
U2: 62256/628128; DIP-32_W15.24mm
U3: 74HC139; DIP-16_W7.62mm
U4: 74HC174; DIP-16_W7.62mm
U5: 74HC4520; DIP-16_W7.62mm
U6: 74HC40103; DIP-16_W7.62mm
U7: 74HC670; DIP-16_W7.62mm

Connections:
/M2: H1.32 (M2)
/R~W: H1.14 (cR~W), U1.31 (PGM), U3.2 (A0)
/ScanlineClk: U5.5 (Q3), U6.1 (CP)
/cA0: H1.13 (cA0), U1.12 (A0), U7.14 (Wa)
/cA1: H1.12 (cA1), U1.11 (A1), U7.13 (Wb)
/cA2: H1.11 (cA2), U1.10 (A2)
/cA3: H1.10 (cA3), U1.9 (A3)
/cA4: H1.9 (cA4), U1.8 (A4)
/cA5: H1.8 (cA5), U1.7 (A5)
/cA6: H1.7 (cA6), U1.6 (A6)
/cA7: H1.6 (cA7), U1.5 (A7)
/cA8: H1.5 (cA8), U1.27 (A8)
/cA9: H1.4 (cA9), U1.26 (A9)
/cA10: H1.3 (cA10), U1.23 (A10)
/cA11: H1.2 (cA11), U1.25 (A11)
/cA12: H1.33 (cA12), U1.4 (A12)
/cA13: H1.34 (cA13), U1.28 (A13), U3.14 (A0)
/cA14: H1.35 (cA14), U1.29 (A14), U3.13 (A1)
/cBank0: U1.3 (A15), U4.2 (Q0)
/cBank1: U1.2 (A16), U4.5 (Q1)
/cBank2: U1.30 (A17), U4.7 (Q2)
/cBank3: U1.1 (A18), U4.10 (Q3)
/cD0: H1.43 (cD0), U1.13 (D0), U4.3 (D0), U6.4 (P0), U7.15 (D1)
/cD1: H1.42 (cD1), U1.14 (D1), U4.4 (D1), U6.5 (P1), U7.1 (D2)
/cD2: H1.41 (cD2), U1.15 (D2), U4.6 (D2), U6.6 (P2), U7.2 (D3)
/cD3: H1.40 (cD3), U1.17 (D3), U4.11 (D3), U6.7 (P3), U7.3 (D4)
/cD4: H1.39 (cD4), U1.18 (D4), U6.10 (P4)
/cD5: H1.38 (cD5), U1.19 (D5), U6.11 (P5)
/cD6: H1.37 (cD6), U1.20 (D6), U4.13 (D4), U6.12 (P6)
/cD7: H1.36 (cD7), U1.21 (D7), U4.14 (D5), U6.13 (P7)
/pA0: H1.25 (pA0), U2.12 (A0)
/pA1: H1.24 (pA1), U2.11 (A1)
/pA2: H1.23 (pA2), U2.10 (A2)
/pA3: H1.22 (pA3), U2.9 (A3)
/pA4: H1.21 (pA4), U2.8 (A4)
/pA5: H1.20 (pA5), U2.7 (A5)
/pA6: H1.19 (pA6), U2.6 (A6)
/pA7: H1.50 (pA7), U2.5 (A7)
/pA8: H1.51 (pA8), U2.27 (A8)
/pA9: H1.52 (pA9), U2.26 (A9)
/pA10: H1.53 (pA10), U2.23 (A10)
/pA11: H1.54 (pA11), RN1.1 (common), U2.31 (A15), U7.5 (Ra)
/pA12: H1.55 (pA12), U2.2 (A16), U7.4 (Rb)
/pA13: H1.56 (pD13), U5.15 (Reset), U7.11 (~Er)
/pBank0: RN1.2 (R1), U2.25 (A11), U7.10 (Q1)
/pBank1: RN1.5 (R4), U2.4 (A12), U7.9 (Q2)
/pBank2: RN1.4 (R3), U2.28 (A13), U7.7 (Q3)
/pBank3: RN1.3 (R2), U2.3 (A14), U7.6 (Q4)
/pD0: H1.26 (pD0), U2.13 (I/O0)
/pD1: H1.27 (pD1), U2.14 (I/O1)
/pD2: H1.28 (pD2), U2.15 (I/O2)
/pD3: H1.29 (pD3), U2.17 (I/O3)
/pD4: H1.60 (pD4), U2.18 (I/O4)
/pD5: H1.59 (pD5), U2.19 (I/O5)
/pD6: H1.58 (pD6), U2.20 (I/O6)
/pD7: H1.57 (pD7), U2.21 (I/O7)
/rfAUDIO: H1.45 (cAUDIO), H1.46 (rfAUDIO)
/~IRQStop: U4.15 (Q5), U6.2 (~MR)
/~IRQ: H1.15 (~IRQ), U6.14 (~TC)
/~ROMSEL: H1.44 (~ROMSEL), U1.22 (CE), U3.3 (A1)
/~chrWR: U3.9 (O3), U7.12 (~Ew)
/~hiR: U1.24 (OE), U3.5 (O1)
/~irqWr: U3.10 (O2), U6.9 (~PL)
/~loR: U3.7 (O3)
/~loW: U3.6 (O2)
/~pRD: H1.17 (p~RD), U2.24 (~OE), U5.2 (~CK/EN), U5.10 (~CK/EN)
/~pWR: H1.47 (p~WR), U2.29 (~WE)
/~prgWR: U3.12 (O0), U4.9 (Cp)
/~samWr: U3.11 (O1)
GND: C1.2, C2.2, C3.2, C4.2, C5.2, C6.2, C7.2, H1.1 (GND), H1.16 (GND), U1.16 (GND), U2.16 (GND), U2.22 (~CS1/~CE1), U3.1 (E), U3.8 (GND), U4.8 (GND), U5.1 (CK/~EN), U5.8 (GND), U6.3 (~TE), U6.8 (GND), U7.8 (GND)
unnamed: U3.4 (O0), U3.15 (E)
unnamed: U5.7 (Reset), U5.9 (CK/~EN), U5.11 (Q1)
VCC: C1.1, C2.1, C3.1, C4.1, C5.1, C6.1, C7.1, H1.18 (vramA10), H1.30 (VCC), H1.31 (VCC), H1.48 (vram~CE), U1.32 (VCC), U2.30 (CS2/CE2), U2.32 (VCC), U3.16 (VCC), U4.1 (~Mr), U4.16 (VCC), U5.16 (VCC), U6.15 (~PE), U6.16 (VCC), U7.16 (VCC)

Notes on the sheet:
BNUY-ROM Mappper
335
321
is.. bbbb
* 2048KiB PRG FLASH (rewrittable), 32KiB Window * 32KiB PRG RAM, 8KiB Window * 32KiB CHR RAM, 4x4KiB Window * Four-Screen Scrolling * Scanline IRQ * SAM2695 Sound Expansion
325
4520B
ADDRESS DECODING
327
339
ppuA13
CHR-RAM
dddd dddd
333
337
.... bbbb
4520A
329
CHR LATCH
323
A Discrete Logic FAMICOM Mapper Featuring:
PRG-ROM
scanline clock timing
PRG LATCH
331
ppu~{RD}
$8000 PRG BANK & CTRL $A000 (sound Registers) $C000 IRQ LOAD $E000-E003 CHR BANK

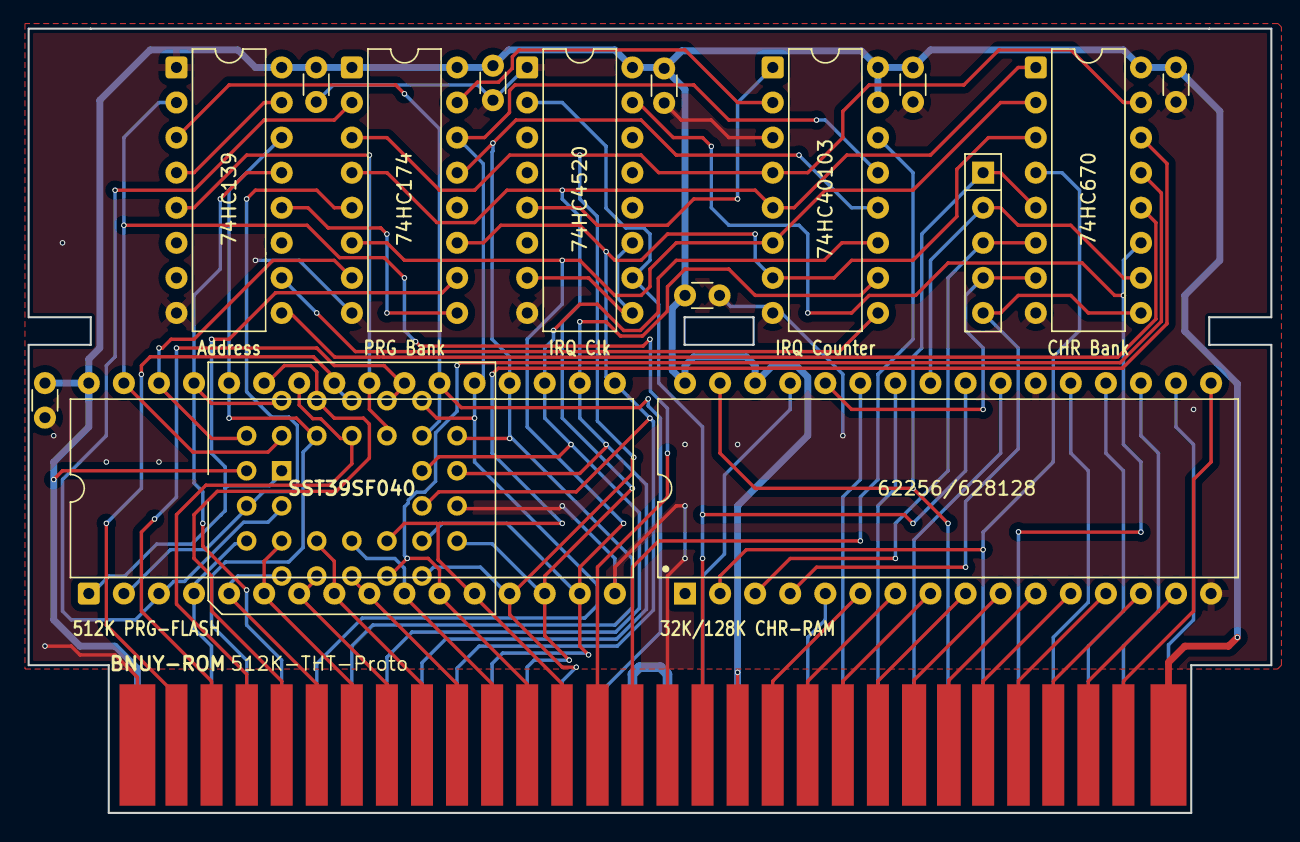
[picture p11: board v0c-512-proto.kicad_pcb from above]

Board: 2 copper layers, 90.0 x 56.8 mm, 16 parts (0 on the bottom side), 69 nets.

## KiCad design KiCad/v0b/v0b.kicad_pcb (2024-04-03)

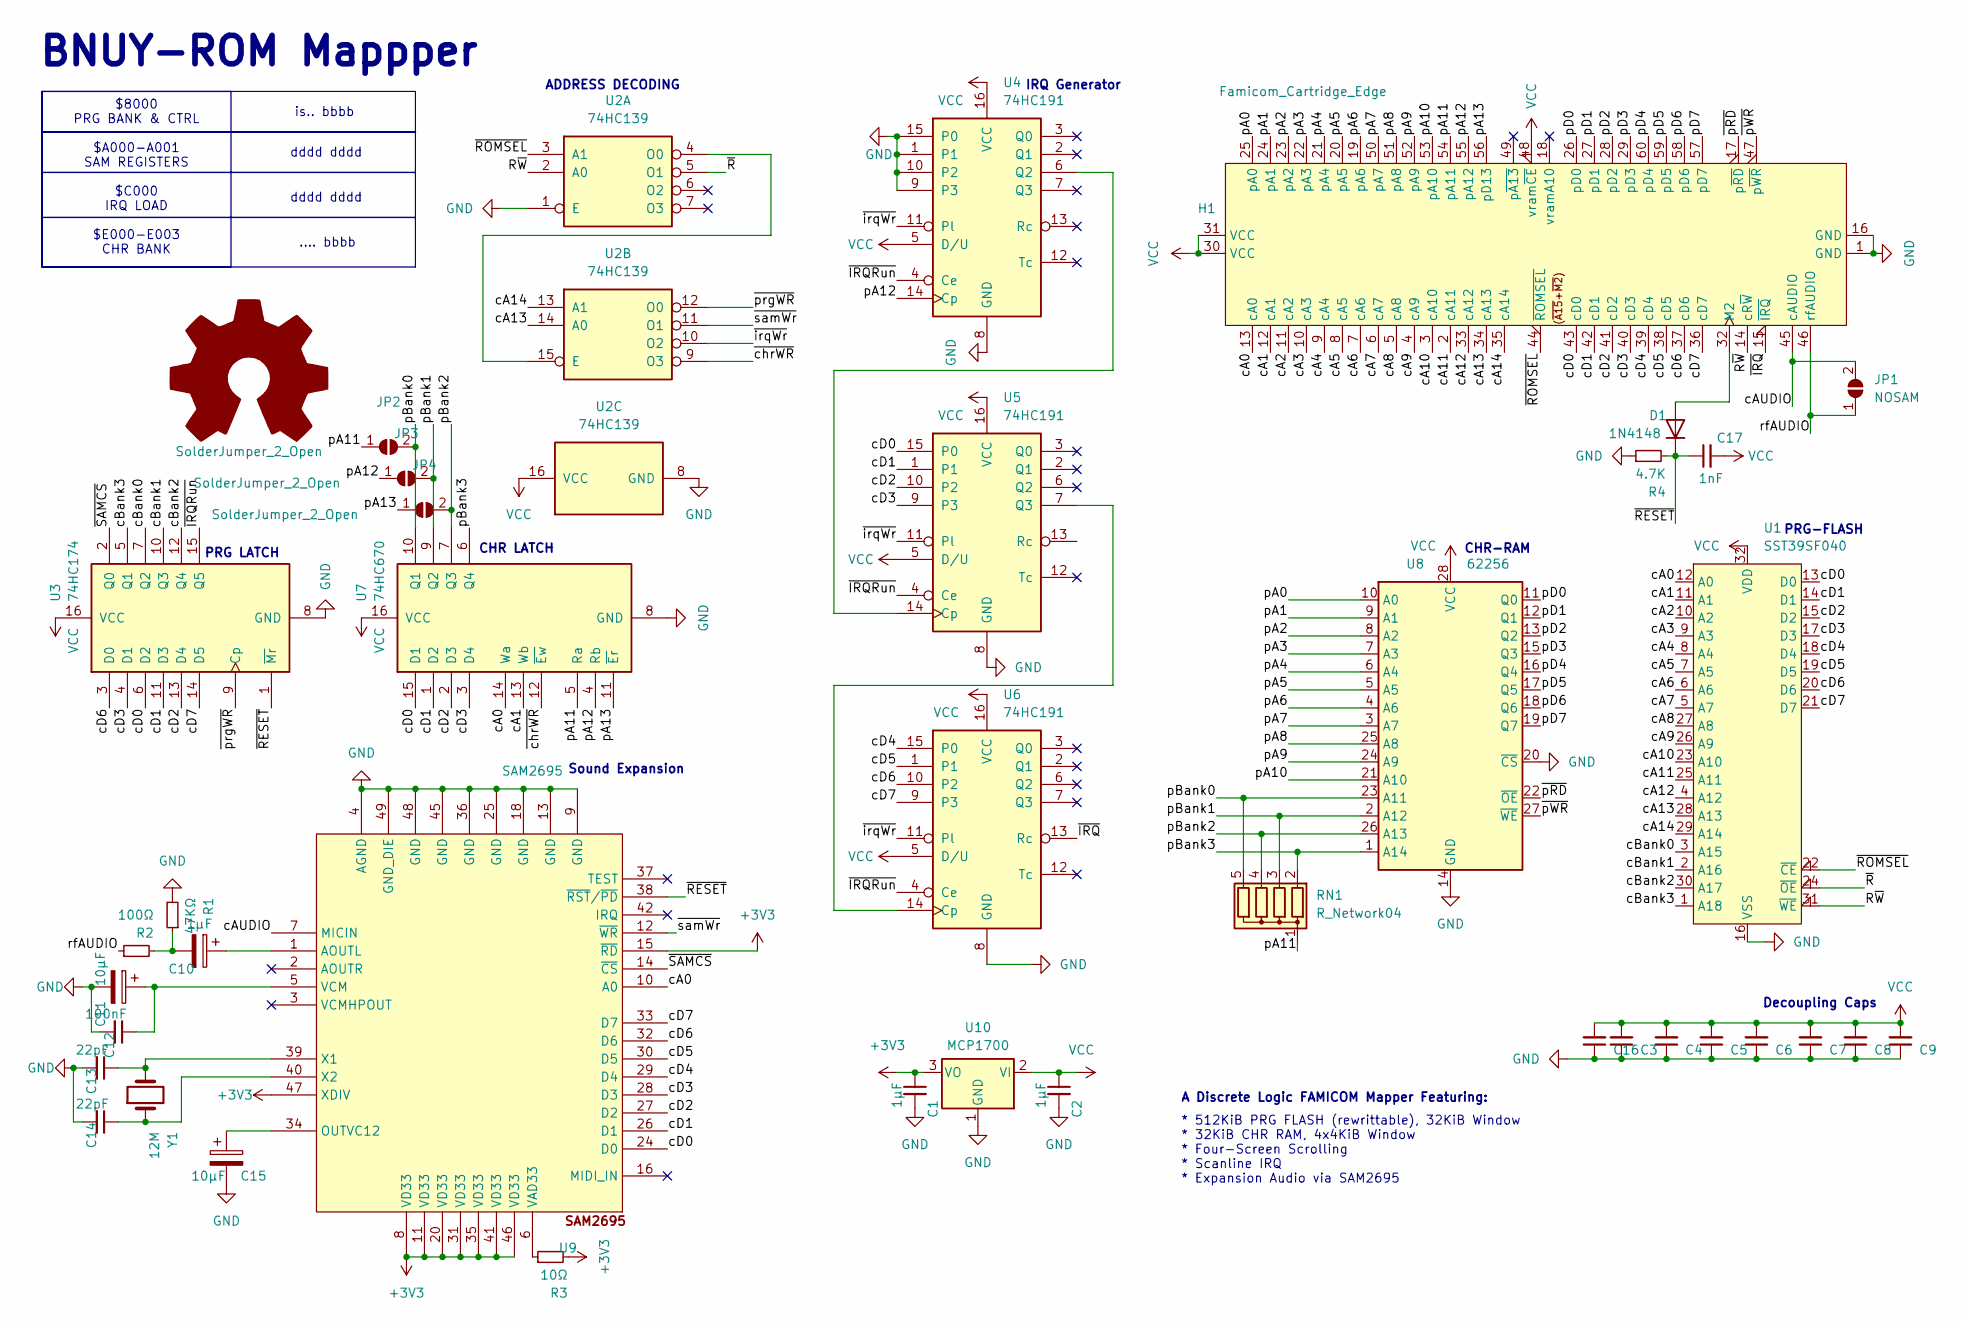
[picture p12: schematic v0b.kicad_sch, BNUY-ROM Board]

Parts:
C1, C2: 1µF; C_Disc_D3.0mm_W1.6mm_P2.50mm
C3, C4, C5, C6, C7, C8, C9, C16: C_Small; C_1206_3216Metric_Pad1.33x1.80mm_HandSolder
C10: 1µF; CP_Radial_D4.0mm_P1.50mm
C11, C15: 10µF; CP_Radial_D4.0mm_P1.50mm
C12: 100nF; C_Disc_D3.0mm_W1.6mm_P2.50mm
C13, C14: 22pF; C_Disc_D3.0mm_W1.6mm_P2.50mm
C17: 1nF; C_Disc_D3.0mm_W1.6mm_P2.50mm
D1: 1N4148; D_DO-34_SOD68_P2.54mm_Vertical_AnodeUp
H1: Famicom_Cartridge_Edge; Famicom Cartridge Edge Connector (long legs)
JP1: NOSAM; SolderJumper-2_P1.3mm_Open_RoundedPad1.0x1.5mm
JP2, JP3, JP4: SolderJumper_2_Open; SolderJumper-2_P1.3mm_Open_RoundedPad1.0x1.5mm
R1: 47KΩ; R_Axial_DIN0204_L3.6mm_D1.6mm_P2.54mm_Vertical
R2: 100Ω; R_Axial_DIN0204_L3.6mm_D1.6mm_P2.54mm_Vertical
R3: 10Ω; R_Axial_DIN0204_L3.6mm_D1.6mm_P2.54mm_Vertical
R4: 4.7K; R_Axial_DIN0204_L3.6mm_D1.6mm_P2.54mm_Vertical
RN1: R_Network04; R_Array_SIP5
U1: SST39SF040; DIP-32_W15.24mm_LongPads
U2: 74HC139; DIP-16_W7.62mm_LongPads
U3: 74HC174; DIP-16_W7.62mm_LongPads
U4, U5, U6: 74HC191; DIP-16_W7.62mm_LongPads
U7: 74HC670; DIP-16_W7.62mm_LongPads
U8: 62256; DIP-28_W15.24mm_LongPads
U9: SAM2695; QFN-48-1EP_6x6mm_P0.4mm_EP4.2x4.2mm_HAND
U10: MCP1700; TO-92_Inline
Y1: 12M; Crystal_HC49-4H_Vertical

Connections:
+3V3: C1.1, R3.2, U9.8 (VD33), U9.11 (VD33), U9.15 (~RD), U9.20 (VD33), U9.31 (VD33), U9.35 (VD33), U9.41 (VD33), U9.46 (VD33), U9.47 (XDIV), U10.3 (VO)
/R~W: H1.14 (cR~W), U1.31 (~WE), U2.2 (A0)
/cA0: H1.13 (cA0), U1.12 (A0), U7.14 (Wa), U9.10 (A0)
/cA1: H1.12 (cA1), U1.11 (A1), U7.13 (Wb)
/cA2: H1.11 (cA2), U1.10 (A2)
/cA3: H1.10 (cA3), U1.9 (A3)
/cA4: H1.9 (cA4), U1.8 (A4)
/cA5: H1.8 (cA5), U1.7 (A5)
/cA6: H1.7 (cA6), U1.6 (A6)
/cA7: H1.6 (cA7), U1.5 (A7)
/cA8: H1.5 (cA8), U1.27 (A8)
/cA9: H1.4 (cA9), U1.26 (A9)
/cA10: H1.3 (cA10), U1.23 (A10)
/cA11: H1.2 (cA11), U1.25 (A11)
/cA12: H1.33 (cA12), U1.4 (A12)
/cA13: H1.34 (cA13), U1.28 (A13), U2.14 (A0)
/cA14: H1.35 (cA14), U1.29 (A14), U2.13 (A1)
/cAUDIO: H1.45 (cAUDIO), JP1.2 (B), U9.7 (MICIN)
/cBank0: U1.3 (A15), U3.7 (Q2)
/cBank1: U1.2 (A16), U3.10 (Q3)
/cBank2: U1.30 (A17), U3.12 (Q4)
/cBank3: U1.1 (A18), U3.5 (Q1)
/cD0: H1.43 (cD0), U1.13 (D0), U3.6 (D2), U5.15 (P0), U7.15 (D1), U9.24 (D0)
/cD1: H1.42 (cD1), U1.14 (D1), U3.11 (D3), U5.1, U7.1 (D2), U9.26 (D1)
/cD2: H1.41 (cD2), U1.15 (D2), U3.13 (D4), U5.10 (P2), U7.2 (D3), U9.27 (D2)
/cD3: H1.40 (cD3), U1.17 (D3), U3.4 (D1), U5.9 (P3), U7.3 (D4), U9.28 (D3)
/cD4: H1.39 (cD4), U1.18 (D4), U6.15 (P0), U9.29 (D4)
/cD5: H1.38 (cD5), U1.19 (D5), U6.1, U9.30 (D5)
/cD6: H1.37 (cD6), U1.20 (D6), U3.3 (D0), U6.10 (P2), U9.32 (D6)
/cD7: H1.36 (cD7), U1.21 (D7), U3.14 (D5), U6.9 (P3), U9.33 (D7)
/pA0: H1.25 (pA0), U8.10 (A0)
/pA1: H1.24 (pA1), U8.9 (A1)
/pA2: H1.23 (pA2), U8.8 (A2)
/pA3: H1.22 (pA3), U8.7 (A3)
/pA4: H1.21 (pA4), U8.6 (A4)
/pA5: H1.20 (pA5), U8.5 (A5)
/pA6: H1.19 (pA6), U8.4 (A6)
/pA7: H1.50 (pA7), U8.3 (A7)
/pA8: H1.51 (pA8), U8.25 (A8)
/pA9: H1.52 (pA9), U8.24 (A9)
/pA10: H1.53 (pA10), U8.21 (A10)
/pA11: H1.54 (pA11), JP2.1 (A), RN1.1 (common), U7.5 (Ra)
/pA12: H1.55 (pA12), JP3.1 (A), U4.14 (Cp), U7.4 (Rb)
/pA13: H1.56 (pD13), JP4.1 (A), U7.11 (~Er)
/pBank0: JP2.2 (B), RN1.5 (R4), U7.10 (Q1), U8.23 (A11)
/pBank1: JP3.2 (B), RN1.3 (R2), U7.9 (Q2), U8.2 (A12)
/pBank2: JP4.2 (B), RN1.4 (R3), U7.7 (Q3), U8.26 (A13)
/pBank3: RN1.2 (R1), U7.6 (Q4), U8.1 (A14)
/pD0: H1.26 (pD0), U8.11 (Q0)
/pD1: H1.27 (pD1), U8.12 (Q1)
/pD2: H1.28 (pD2), U8.13 (Q2)
/pD3: H1.29 (pD3), U8.15 (Q3)
/pD4: H1.60 (pD4), U8.16 (Q4)
/pD5: H1.59 (pD5), U8.17 (Q5)
/pD6: H1.58 (pD6), U8.18 (Q6)
/pD7: H1.57 (pD7), U8.19 (Q7)
/rfAUDIO: H1.46 (rfAUDIO), JP1.1 (A), R2.1
/~IRQRun: U3.15 (Q5), U4.4 (Ce), U5.4 (Ce), U6.4 (Ce)
/~IRQ: H1.15 (~IRQ), U6.13 (Rc)
/~RESET: C17.1, D1.1 (K), R4.2, U3.1 (~Mr), U9.38 (~RST/~PD)
/~ROMSEL: H1.44 (~ROMSEL), U1.22 (~CE), U2.3 (A1)
/~R: U1.24 (~OE), U2.5 (O1)
/~SAMCS: U3.2 (Q0), U9.14 (~CS)
/~chrWR: U2.9 (O3), U7.12 (~Ew)
/~irqWr: U2.10 (O2), U4.11 (Pl), U5.11 (Pl), U6.11 (Pl)
/~pRD: H1.17 (p~RD), U8.22 (~OE)
/~pWR: H1.47 (p~WR), U8.27 (~WE)
/~prgWR: U2.12 (O0), U3.9 (Cp)
/~samWr: U2.11 (O1), U9.12 (~WR)
GND: C1.2, C2.2, C3.1, C4.1, C5.1, C6.1, C7.1, C8.1, C9.1, C11.2, C12.2, C13.2, C14.2, C15.2, C16.1, H1.1 (GND), H1.16 (GND), R1.2, R4.1, U1.16 (VSS), U2.1 (E), U2.8 (GND), U3.8 (GND), U4.1, U4.8 (GND), U4.9 (P3), U4.10 (P2), U4.15 (P0), U5.8 (GND), U6.8 (GND), U7.8 (GND), U8.14 (GND), U8.20 (~CS), U9.4 (AGND), U9.9 (GND), U9.13 (GND), U9.18 (GND), U9.25 (GND), U9.36 (GND), U9.45 (GND), U9.48 (GND), U9.49 (GND_DIE), U10.1 (GND)
unnamed: C10.2, R1.1, R2.2
unnamed: D1.2 (A), H1.32 (M2)
unnamed: U2.4 (O0), U2.15 (E)
unnamed: U4.6 (Q2), U5.14 (Cp)
unnamed: U5.7 (Q3), U6.14 (Cp)
unnamed: C10.1, U9.1 (AOUTL)
unnamed: C15.1, U9.34 (OUTVC12)
unnamed: R3.1, U9.6 (VAD33)
unnamed: C11.1, C12.1, U9.5 (VCM)
unnamed: C13.1, U9.39 (X1), Y1.2
unnamed: C14.1, U9.40 (X2), Y1.1
VCC: C2.1, C3.2, C4.2, C5.2, C6.2, C7.2, C8.2, C9.2, C16.2, C17.2, H1.30 (VCC), H1.31 (VCC), H1.48 (vram~CE), U1.32 (VDD), U2.16 (VCC), U3.16 (VCC), U4.5 (D/U), U4.16 (VCC), U5.5 (D/U), U5.16 (VCC), U6.5 (D/U), U6.16 (VCC), U7.16 (VCC), U8.28 (VCC), U10.2 (VI)

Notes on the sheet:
$8000 PRG BANK & CTRL $A000-A001 SAM REGISTERS $C000 IRQ LOAD $E000-E003 CHR BANK
BNUY-ROM Mappper
is.. bbbb
* 512KiB PRG FLASH (rewrittable), 32KiB Window * 32KiB CHR RAM, 4x4KiB Window * Four-Screen Scrolling * Scanline IRQ * Expansion Audio via SAM2695
ADDRESS DECODING
CHR-RAM
dddd dddd
.... bbbb
CHR LATCH
A Discrete Logic FAMICOM Mapper Featuring:
Decoupling Caps
PRG-FLASH
PRG LATCH
Sound Expansion
IRQ Generator

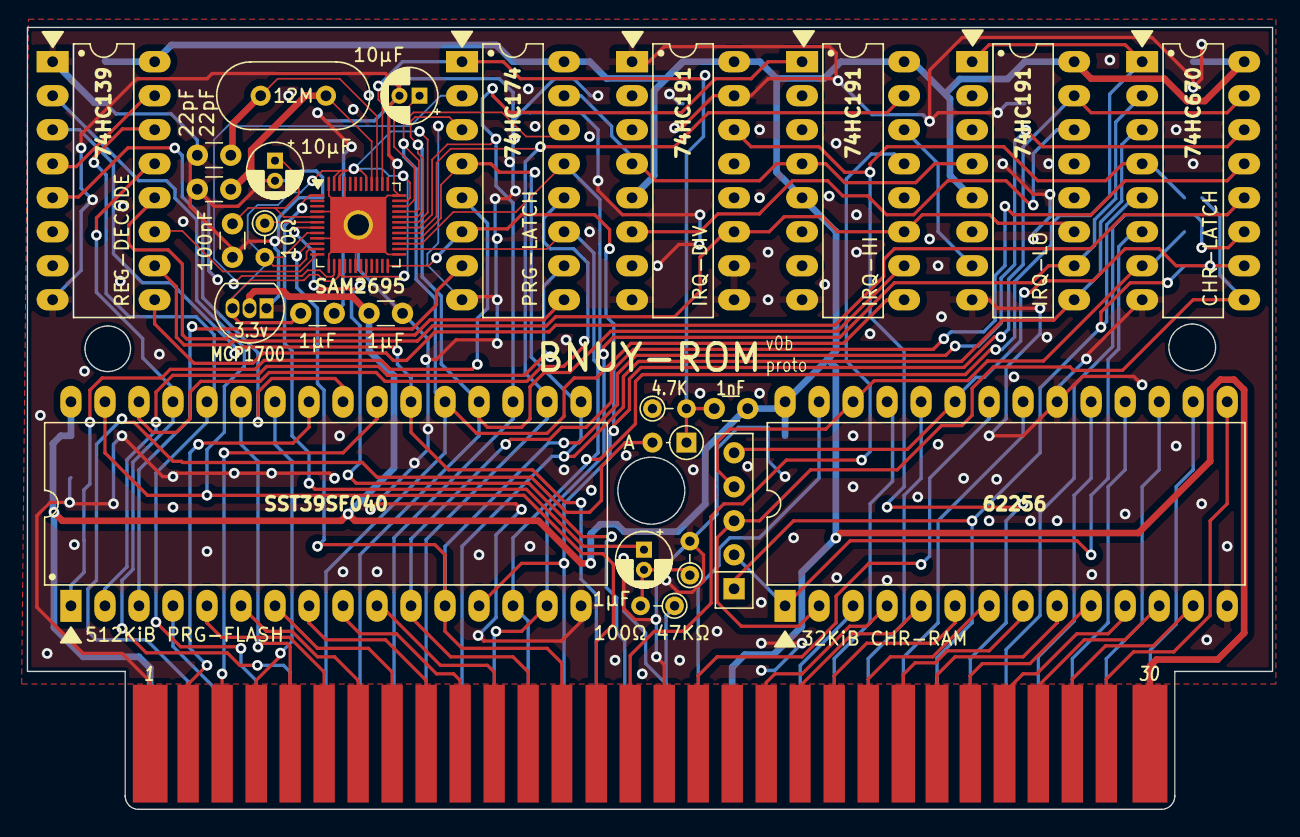
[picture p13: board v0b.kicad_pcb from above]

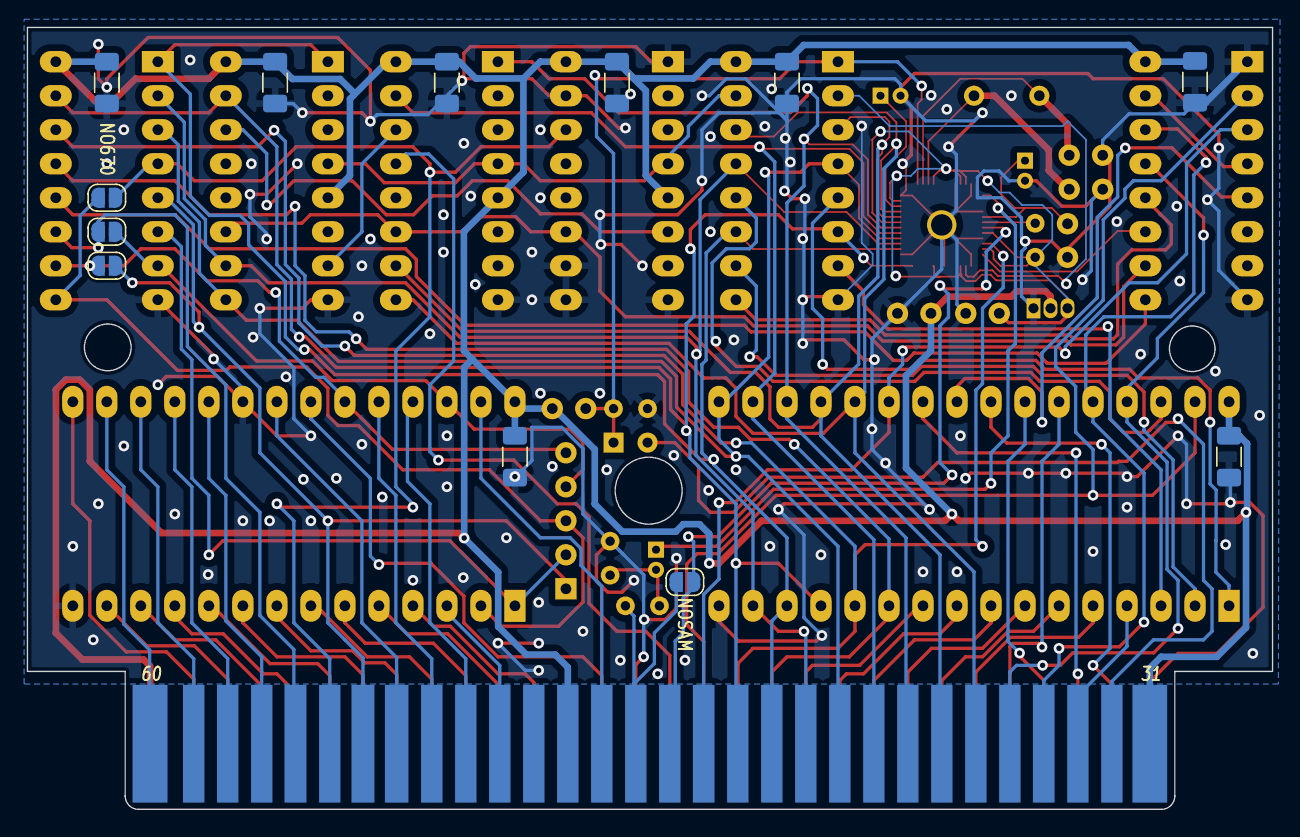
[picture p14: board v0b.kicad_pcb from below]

Board: 2 copper layers, 93.0 x 58.4 mm, 39 parts (12 on the bottom side), 82 nets.

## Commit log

2024-03-09 Add pcb files
    [v0a-B_Adhesive.gbr, v0a-B_Cu.gbr, v0a-B_Fab.gbr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]
2024-03-31 v0b update
    [v0b.kicad_pcb, v0b.kicad_sch]
2024-04-01 update v0b and README documentation
    [v0b.kicad_pcb, v0b.kicad_sch]
2024-04-03 update v0b
    [v0b.kicad_pcb, v0b.kicad_sch]
2025-04-03 Update README, v0b schematic
    [v0b.kicad_sch]
2025-06-04 initial v0c update
    [v0c.kicad_pcb, v0c.kicad_sch]
2025-06-06 sam2695 on board
    [v0c.kicad_pcb, v0c.kicad_sch]
2025-06-06 Silkscreen and schematic tweaks
    [sound.kicad_sch, v0c.kicad_pcb, v0c.kicad_sch]
2025-06-30 Change Scanline Circuit
    [v0c.kicad_pcb, v0c.kicad_sch]
2025-07-10 Update pcbs and readme
    [sound.kicad_sch, v0c-512-proto.kicad_pcb, v0c-512-proto.kicad_sch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]
2025-07-29 Fix broken commit
    [sound.kicad_sch, v0a.kicad_pcb, v0a.kicad_sch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]
2025-07-30 fix issues
    [v0d-512-proto.kicad_pcb, v0d-512-proto.kicad_sch]
2025-08-05 v0d smd board
    [sound.kicad_sch, v0d-2048-32.kicad_pcb, v0d-2048-32.kicad_sch]
2025-08-05 schematic tweak
    [v0d-2048-32.kicad_sch]
2026-01-14 Update to latest pcb version, README tweaks
    [v0a-B_Adhesive.gbr, v0a-B_Cu.gbr, v0a-B_Fab.gbr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]
2026-01-17 add battery bit flag to README
